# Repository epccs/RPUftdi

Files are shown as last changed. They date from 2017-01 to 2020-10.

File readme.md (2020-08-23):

# RPUusb

From <https://github.com/epccs/RPUusb>

## Overview

Alow a desktop or other host with USB to interface with [Gravimetric] that have an R-Pi header. It has two UARTs that can together operate the multi-drop serial. 

[Gravimetric]: https://github.com/epccs/Gravimetric

## Status

This board has a known problem with managers that lack power domains that allow one side to power down, that is to say if it has power and the application does not then the manager on the application board will be damaged. It is my hope that I can figure out how to use one of the new AVR-DB chips as a manager to fix this problem.

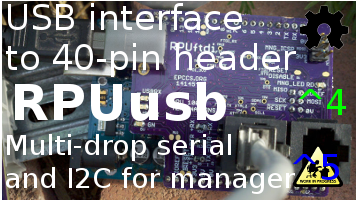
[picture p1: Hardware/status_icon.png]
Status


This is programmed with an in-circuit serial programming tool that is able to handle the 3.3V ATmega328pb target. I use an Arduino Uno with the [ArduinoISP] sketch and an SPI level shifter.

[ICSP]: https://github.com/epccs/Driver/tree/master/ICSP

[ArduinoISP]: https://github.com/arduino/Arduino/blob/master/build/shared/examples/11.ArduinoISP/ArduinoISP/ArduinoISP.ino

## [Hardware](./Hardware)

Hardware files and notes for referance.

## Example

TBD

## AVR toolchain

The core files for this board are in the /lib folder. Each example has its files and a Makefile in its own folder. The toolchain packages that I use are available on Ubuntu, Raspbian and Windows with WSL and Ubuntu installed. 

```
sudo apt-get install git make gcc-avr binutils-avr gdb-avr avr-libc avrdude
git clone https://github.com/epccs/RPUusb
```

* [gcc-avr](https://packages.ubuntu.com/search?keywords=gcc-avr)
* [binutils-avr](https://packages.ubuntu.com/search?keywords=binutils-avr)
* [gdb-avr](https://packages.ubuntu.com/search?keywords=gdb-avr)
* [avr-libc](https://packages.ubuntu.com/search?keywords=avr-libc)
* [avrdude](https://packages.ubuntu.com/search?keywords=avrdude)

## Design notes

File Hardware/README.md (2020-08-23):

# Hardware

## Overview

USB interface that plugs in place of an R-Pi. It plugs into an R-Pi header (e.g., [Gravimetric]). The CP2105 chip has two UARTs. The full-duplex multidrop bus is directly connected to the primary UART, while the secondary UART is connected to an MCU (ATmega328pb) that can act as a bridge for many of the R-Pi header pins (e.g., SPI, I2C) from the target board. A USB host can set the bootload address on the multi-drop serial with the I2C interface from the 328pb, and some other functions that an R-Pi has access to from the manager.

[Gravimetric]: https://github.com/epccs/Gravimetric

## Inputs/Outputs/Functions

* Full Duplex TX and RX from USB serial0 on R-Pi header pin 8 and 10.
* RTS and CTS from USB serial0 on R-Pi header pin 36 and 11.
* USB serial1 connects with an ATmega328pb for use with I2C/SPI.
* Fits RPUpi or Gravimetric.

## Uses

* Plugs in place of an R-Pi to allow USB from a computer to communicate with an RPU target.

# Table Of Contents

1. [Status](#status)
2. [Design](#design)
3. [Bill of Materials](#bill-of-materials)
4. [How To Use](#how-to-use)

# Status

Status RPUusb Status

```
        ^5  Done: Design (# = done), Layout, BOM, Review*, Order Boards, Assembly, Testing,
            WIP: Evaluation.
            Todo: 
            *during review the Design may change without changing the revision.
            High risk of damage to manager on application board, if manager has dual power domains that may fix
            # remove arduino headers
            # add header with 40 pin R-Pi pinout
            # swap MCU to ATmega328pb
            # swap ftdi with a dual UART port version Silabs CP2105
            # connect serial0 to RX/TX/nRTS/nCTS on R-Pi header
            # connect sierial1 to MCU's serial0
            # connect MCU's I2C0 to I2C on R-Pi header
            # connect MCU's I2C1 to the ID port on R-Pi header
            # connect MCU's SPI to SPI on R-Pi header
            # power with 3V3 from LDO and power the LDO from the USB header through the P-CH soft start. 

        ^4 Done: Design, Layout, BOM, Review*, Order Boards, Assembly, Testing, Evaluation.
           WIP: 
           Todo:  
           *during review the Design may change without changing the revision.
           location: 2017-3-17 Test Bench /w an OSEPP Uno R3

        ^3 location: 2016-10-1 Test Bench /w an OSEPP Uno R3, used to connect by CAT5 to outside parts and to bench parts as needed.
                     2017-1-5 ICP1 hacked open.
                     2017-3-17 scraped
```

Debugging and fixing problems i.e. [Schooling](./Schooling/)

Setup and methods used for [Evaluation](./Evaluation/)

# Design

The board is 0.063 thick, FR4, two layer, 1 oz copper with ENIG (gold) finish.

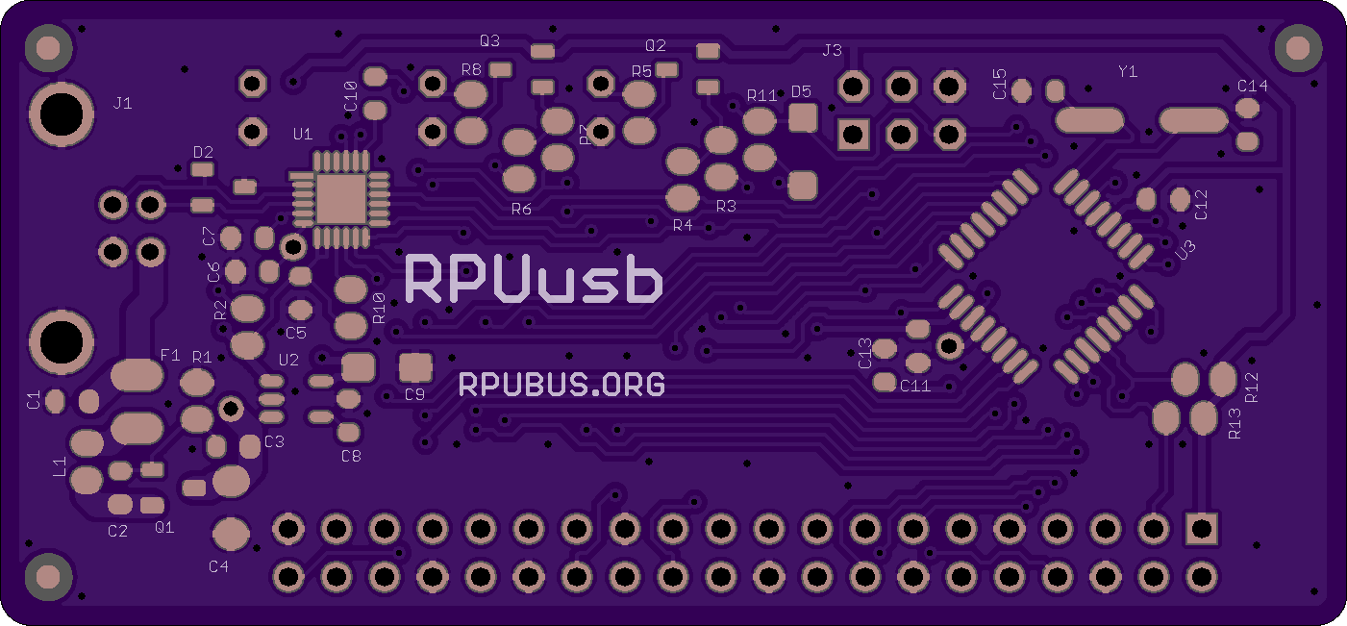
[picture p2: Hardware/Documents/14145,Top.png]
Top RPUusb Top

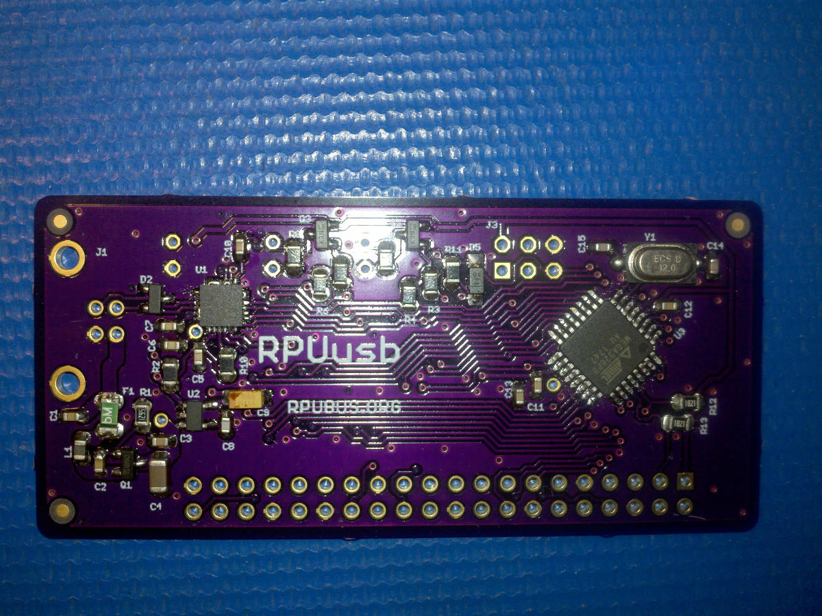
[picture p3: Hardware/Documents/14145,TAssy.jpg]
TAssy RPUusb Top Assy

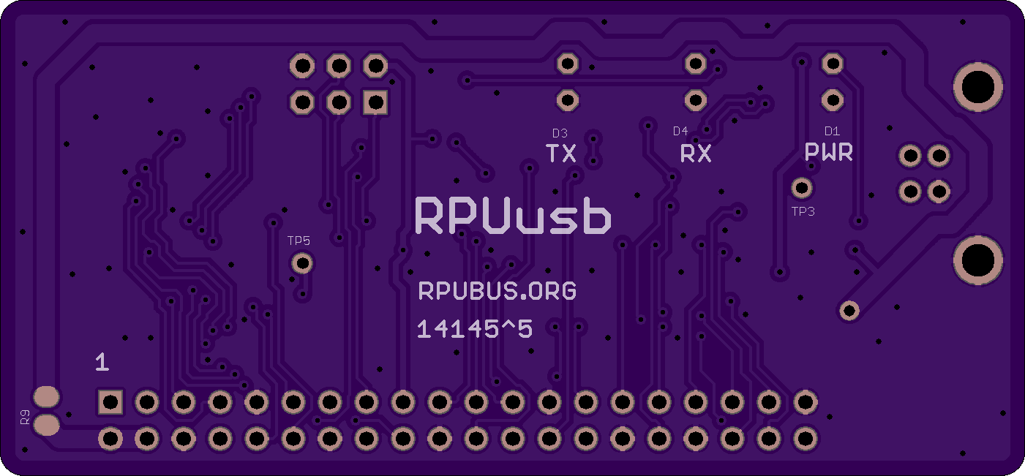
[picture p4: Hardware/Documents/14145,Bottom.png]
Bottom RPUusb Bottom

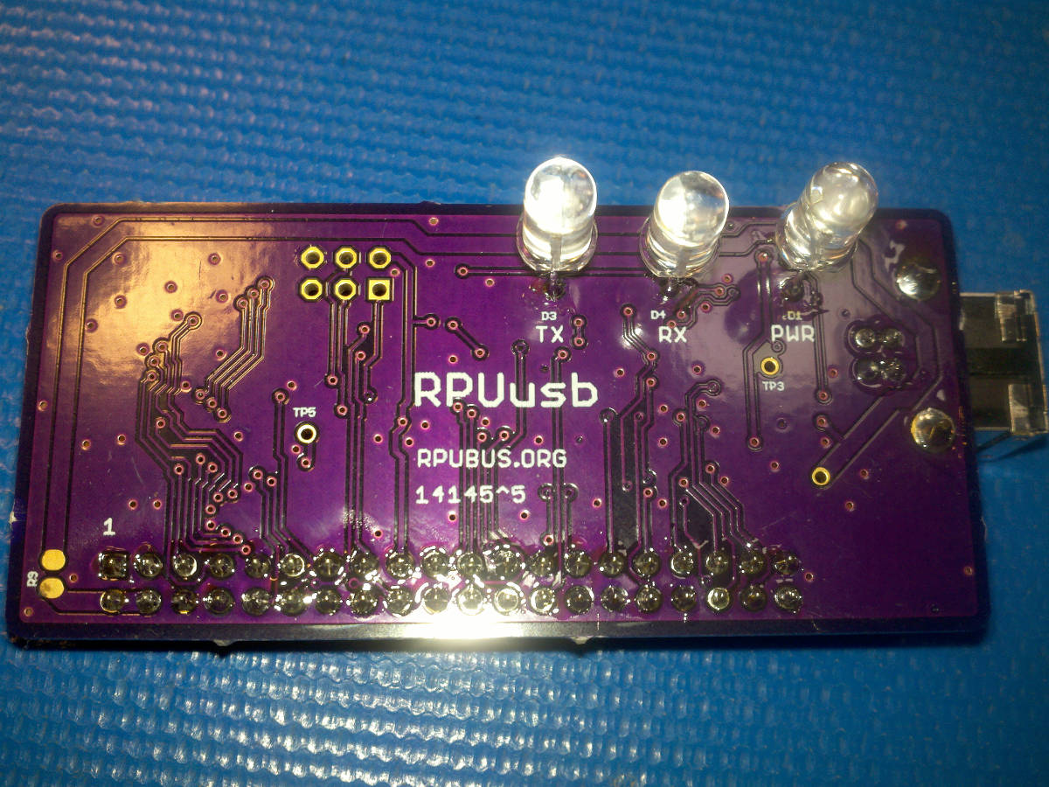
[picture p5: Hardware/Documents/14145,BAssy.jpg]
BAssy RPUusb Bottom Assy


## Mounting

```
        Plugs into the R-Pi header of a multi-drop serial board.
```

## Electrical Schematic

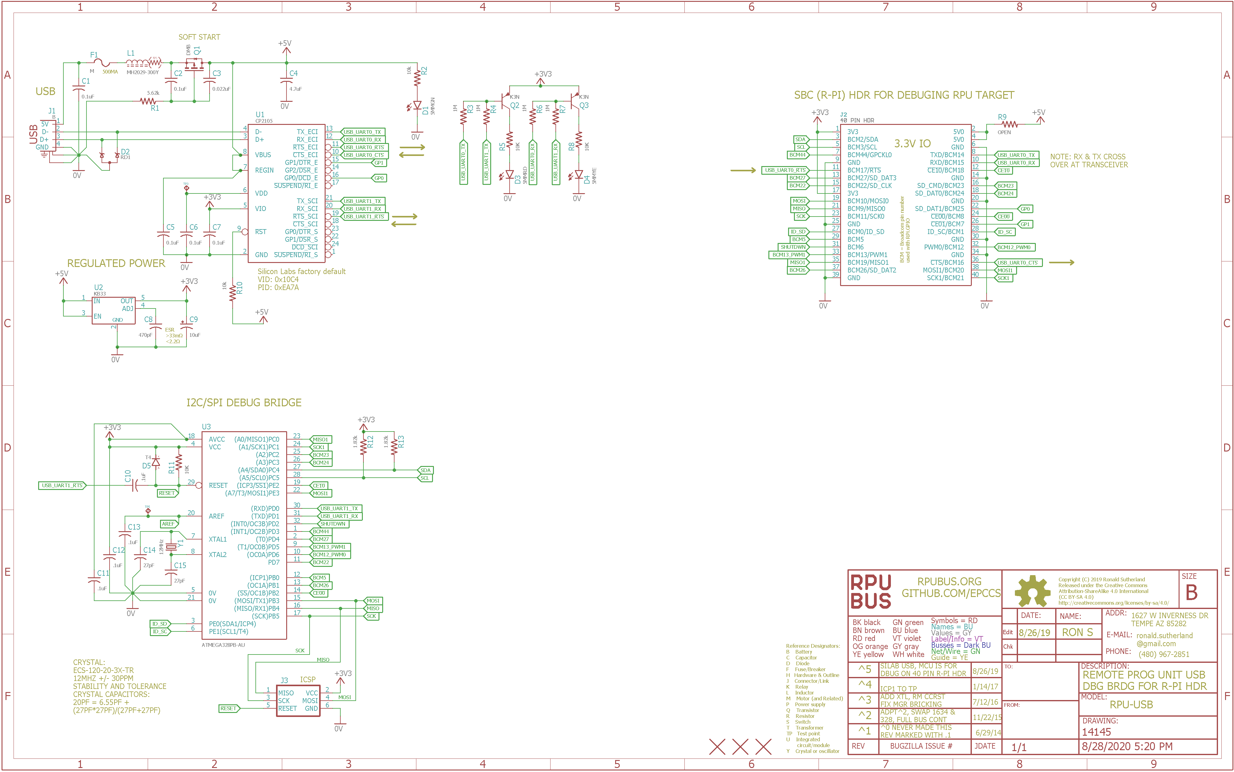
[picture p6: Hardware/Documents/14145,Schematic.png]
Schematic RPUusb Schematic


## Testing

Check correct assembly and function with [Testing](./Testing/)

# Bill of Materials

The BOM is a CVS file, import it into a spreadsheet program like LibreOffice Calc (or Excel), or use a text editor.

Option | BOM's included
----- | ----- 
A. | [BRD] 
M. | [BRD] [SMD] [HDR] 

[BRD]: ./Design/14145BRD,BOM.csv
[SMD]: ./Design/14145SMD,BOM.csv
[HDR]: ./Design/14145HDR,BOM.csv

[Order Form](https://rpubus.org/Order_Form.html)

# How To Use

TDD

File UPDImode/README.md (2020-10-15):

# UPDI mode

## Overview

The BCM23 and BCM24 pins are used by my PiUPDI board to select serial0 and UPDI programing. PiUPDI has an AVR128DA28 that is programed with [pyupdi].

[pyupdi]: https://github.com/mraardvark/pyupdi/

## Firmware Upload

Use the secondary serial port connection (see BOOTLOAD_PORT in Makefile) to reset the MCU and execute optiboot so that the 'make bootload' rule can upload a new binary image in the application area of flash memory. The bootloader runs at 38.4kbps.

``` 
sudo apt-get install make git picocom gcc-avr binutils-avr gdb-avr avr-libc avrdude
git clone https://github.com/epccs/RPUusb/
cd /Gravimetric/Applications/BCM24cntl
make all
...
avr-objcopy -j .text -j .data -O ihex blinkLED.elf blinkLED.hex
avr-objdump -h -S blinkLED.elf > blinkLED.lst
make bootload
...
avrdude done.  Thank you.
``` 

Now connect with picocom (or ilk) to send commands.

``` 
picocom -b 38400 /dev/ttyUSB1
...
/0/id?
{"id":{"name":"BMC24cntl","desc":"RPUusb (14145^5) Board /w ATmega328pb","avr-gcc":"5.4.0"}}
/0/updi
{"PiUPDI":"UPDI"}
/0/uart
{"PiUPDI":"UART"}
#exit is C-a, C-x
``` 

The Python program will need to be done so it can reconize if a R-Pi is in use or if it is an RPUusb.

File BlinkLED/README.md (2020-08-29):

# Makefile based non-blocking Blink

## Overview

Demonstration of General I/O, e.g. Blink an LED. 

It also links an Interrupt-Driven UART library for AVR Standard IO facilities, as well as some Python that sends an 'a' character to stop blinking the SCK pin. 

## Firmware Upload

Use the secondary serial port connection (see BOOTLOAD_PORT in Makefile) to reset the MCU and execute optiboot so that the 'make bootload' rule can upload a new binary image in the application area of flash memory. The bootloader runs at 38.4kbps.

``` 
sudo apt-get install make git picocom gcc-avr binutils-avr gdb-avr avr-libc avrdude
git clone https://github.com/epccs/RPUusb/
cd /RPUusb/Applications/BlinkLED
make all
...
avr-objcopy -j .text -j .data -O ihex blinkLED.elf blinkLED.hex
avr-objdump -h -S blinkLED.elf > blinkLED.lst
make bootload
...
avrdude done.  Thank you.
``` 

Next use picocom to send characters, an 'a' to stop the blinking of the SCK pin (there is no LED), characters also echo.

``` 
picocom -b 38400 /dev/ttyUSB1
...
a
#exit is C-a, C-x
```

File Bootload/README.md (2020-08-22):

# Serial Bootloader

## Overview

AVR microcontrollers are usually programmed through an In-circuit Serial Programmer (ICSP/ISP), however with this firmware loaded in your microcontroller programing can be done over a serial interface (TX/RX) without the ICSP programmer. This is called serial bootloading. 

Unfortunalty to install a serial bootloader requires an ICSP tool. Arduino has an [ArduinoISP] sketch that I load into a Arduino Uno to use as an ICSP tool.

[ArduinoISP]: https://github.com/arduino/Arduino/blob/master/build/shared/examples/11.ArduinoISP/ArduinoISP/ArduinoISP.ino

It is a two step process. First run "make fuse" which will unlock the boot flash section and set fuses (LOW, HIGH, EXTENDED). The changed fuse setting will switch operation form the internal oscilator to the exteranl crystal, if it is missing the MCU will be locked up. The second step is "make isp" which will load the bootloader and lock the boot flash section, which should prohibit the Store Program Memory (SPM) instruction from running in the boot flash section. 

    WARNING: programing these fuse valuse will lock up the MCU when the crystal is missing or damaged.

## License 

The main.c is GPL while boot.h is BSD (since the code is the documentation just read the license in it).

## Firmware Upload

With ISP tool connected.

``` 
sudo apt-get install make git gcc-avr binutils-avr gdb-avr avr-libc avrdude
git clone https://github.com/epccs/RPUusb/Bootloader
cd /RPUno/Bootloader
make all
make isp
...
avrdude -v -p atmega328pb -C +../lib/avrdude/328pb.conf -c stk500v1 -P /dev/ttyACM0 -b 19200 -U eeprom:r:optiboot_rpuusb_atmega328pb_eeprom.hex:i
...
avrdude: safemode: Fuses OK (E:FD, H:DE, L:FF)
...
avrdude -v -p atmega328pb -C +../lib/avrdude/328pb.conf -c stk500v1 -P /dev/ttyACM0 -b 19200 -e -U lock:w:0xFF:m -U lfuse:w:0xFF:m -U hfuse:w:0xDE:m -U efuse:w:0xFD:m
...
avrdude: safemode: Fuses OK (E:FD, H:DE, L:FF)
...
avrdude -v -p atmega328pb -C +../lib/avrdude/328pb.conf -c stk500v1 -P /dev/ttyACM0 -b 19200 -e -U flash:w:optiboot_rpuusb_atmega328pb_-b38400UL_F_CPU12000000UL.hex -U lock:w:0xEF:m
...
avrdude done.  Thank you.
``` 

The bootloader is from MCUdude
https://github.com/MCUdude/optiboot_flash

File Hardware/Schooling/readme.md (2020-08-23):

# Description

Some lessons I learned doing RPUusb.

# Table Of Contents:

1. ^5 Smoke
1. ^5 Names
1. ^4 Power Chopping
1. ^3 Baud Rate
1. ^3 Bus Manager ICP1 Used to Hault Host
1. ^3 FT231X Problem Toggling nDTR and nRTS
1. ^2 I2C Level Converter
1. ^2 Brick Bus Management MCU

## ^5 Smoke

Do not power the RPUusb board (e.g., so remove the USB plug before) first. Power the application (Gravimetric) board and then plug in the USB. This problem is going to take some time to understand. First, I have to figure out which part(s) let out smoke; it is not apparent.

Found a damaged place, it is the manager (m328pb on Gravimetric^2) over the power pin four, which has a bump above it where the smoke was let out. I have found a few paths (TWI1 which is used for SMBus) where the current from RPUusb could flow into an unpowered manager. I suspect that when I had the USB powered and the Gravimetric unpowered, it damaged the manager, and when I powered the Gravimetric, the manager let out its smoke since it was degraded. I think this could happen without severely damaging other parts, so I will try to replace the Gravimetric manager.

This is probably when a second power domain on an MCU makes  sense. The new AVR-DB series offers it but that will need to be an update, also I think it will need to be the manager on Gravimetric that gets the update.

Replaceing the manager on Gravimetric did fix the problem so if a AVR-DB has two I2C ports on sepreate power domains than I may be fix this. An externaly powered R-Pi would have the same problem I suspect, so this needs fixed (but not on the RPUusb board, it needs fixed on the application board.)

## ^5 Names

RPUftdi has been renamed RPUusb because I am not using an FTDI chip for this. It was probably a bad idea to use the company name in the board name like that.

## ^4 Power Chopping

Transceivers start and stop (chop) the power flow over the USB cable; occasionally it results in a reset of the host computer. Mixing power and data is risky; the next version of this board should not power the transceivers from the USB.

## ^3 Baud Rate 

The [Bit Rate] error at 115.2k is too high (though it mostly works). I have not seen errors on Windows yet but am seeing them on Linux. Looking at the [Rate Calculator] I see 76.8k is very good, but the picocom packaged on Ubuntu does not support it. The next very good rate is 38.4k which picocom does support. The bootloader does a CRC check with each line in the hex file so running it 115.2k is fine, it will redo the chunks with errors. However, I don't want to see any errors while running commands (that would look bad during a demo).

Note: [Baud] is the wrong term, but is the one everyone knows.

[Rate Calculator]: http://wormfood.net/avrbaudcalc.php
[Baud]: https://en.wikipedia.org/wiki/Baud
[Bit Rate]: https://en.wikipedia.org/wiki/Bit_rate#Gross_bit_rate

## ^3 Bus Manager ICP1 Used to Hault Host

Connect bus manager ICP1 pin to a test point rather than DTR transceiver. RPUpi is using it to shutdown/halt the host computer. Cut the indicated PCB trace to open the ICP1 pin.

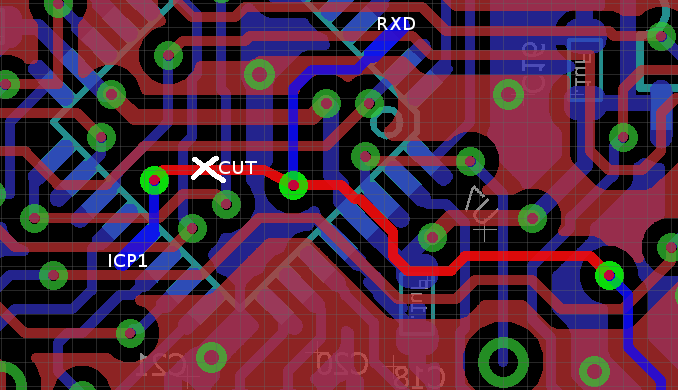
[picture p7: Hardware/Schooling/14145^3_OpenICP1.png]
Open ICP1


## ^3 FT231X Problem Toggling nDTR and nRTS

This problem is not hardware, it was caused because I wrote the Host2Local firmware as though nSS was connected to nRESET directly but that is not the case. I have an open drain buffer between them so when  nSS went high impedance it did not pull up the buffer and the MCU did not turn on after reset. I am still confused why nDTR and nRTS did not pull up but they seem to be working as expected (on both Linux and Windows) now that I set nSS as an output with a high and low state (as opposed to a low and high-z state).

## ^2 I2C Level Converter

If I2C has a pull-up to 3.3V then the level converter is not needed. Arduino's IDE Wire C++ class turns on the ATmega328 internal pull-ups which raise the voltage above 3.3, e.g. I read 3.5V for an undriven bus, which is probably fine but it confused and was not expected. After un-wrapping the TWI code from the Wire class and getting it to run with the vanilla avr-libc I found the pull-up code and turned it into an option during initialization.

## ^2 Brick Bus Management MCU

R20 (jumpered by default) was used to connect a local MCU (SS from a Uno) to reset the bus manager. Unfortunaly when the bootloader programs the local boad it seems to play with the SPI interface and ends up setting the flages of the bus manager to zero. This effectivly bricks the part, though the flags can be set with a parall programing setup (which I may do after collecting a few bricks).

SPI to the bus manager has been removed.

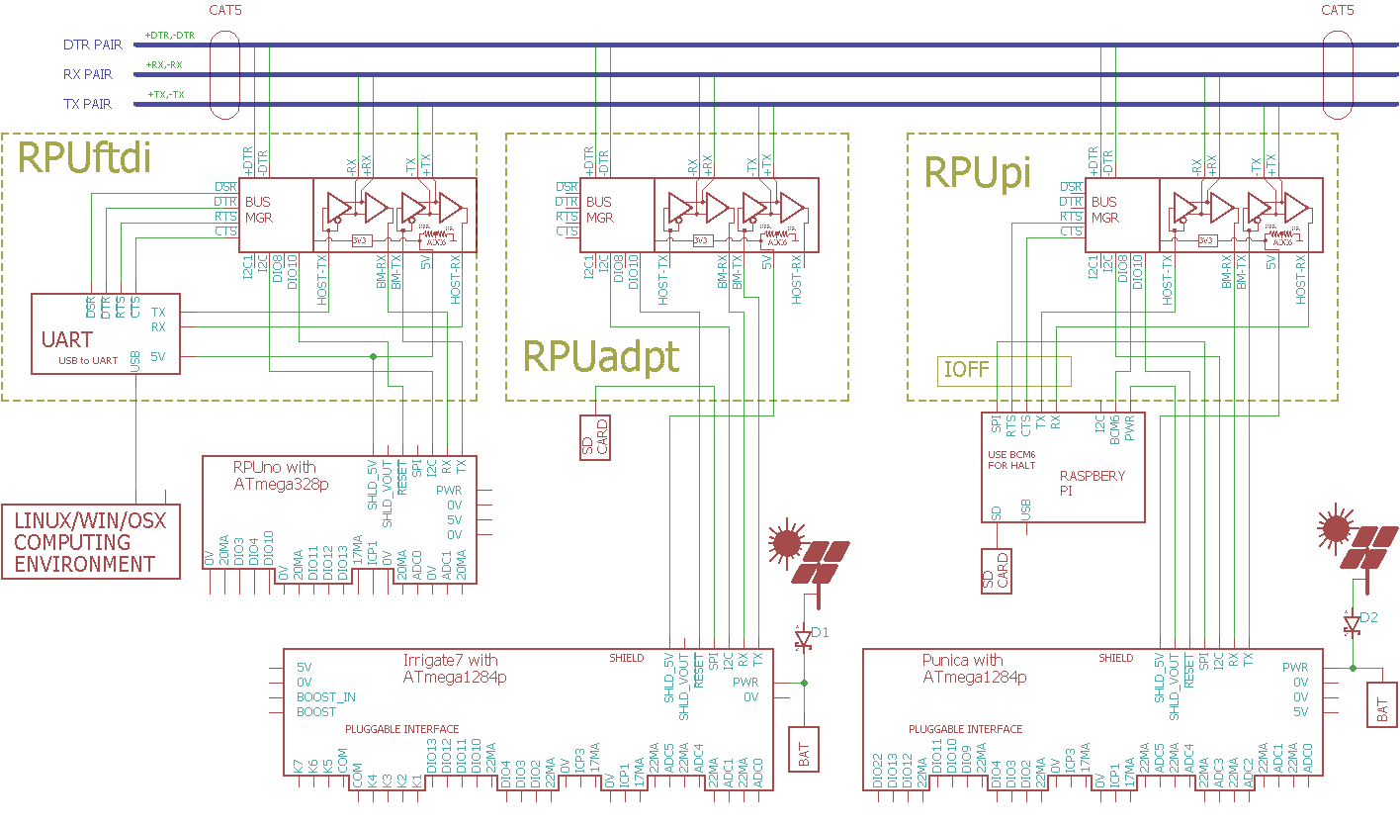
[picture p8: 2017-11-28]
Hardware/Documents/MultiDrop.png

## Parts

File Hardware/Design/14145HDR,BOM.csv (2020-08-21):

LINE | REF | QTY | TYP | PN | MFG@PN | DESCRIPTION | NOTES | COST EA | LINE COST | BIN
 |  |  |  |  |  | RPUusb Headers |  |  | TOTAL
 |  |  |  |  |  | 8/29/19 (14145^5) |  |  | =SUM(J5:J100)
1 | D1 | 1 | D-LED | 5MMGN | CREE@C503B-GCN-CY0C0791 | LED GREEN 5MM 3.2V@20MA | (1) | 0.21 | =C5*I5 | ONESHOT
2 | D3 | 1 | D-LED | 5MMRD | CREE@C503B-RCN-CW0Z0AA1 | LED RED 5MM 2.1V@20MA | (1) | 0.129 | =C6*I6 | ONESHOT
3 | D4 | 1 | D-LED | 5MMYE | CREE@C503B-AAN-CA0B0342 | LED AMBER 5MM 2.1V@20MA | (1) | 0.1342 | =C7*I7 | SHOP
4 | J1 | =1 | J-USB | B | MOLEX@0670688000 | USB B THROUGH HOLE | (1) | 1.199 | =C8*I8 | FTDI
5 | J2 | =1*20/36 | J-HDR2.54mm | PBC36DAAN | SULLINS@PBC36DAAN | CONN HEADER MALE BRKWAY .1IN AA 36X2POS 1 SET OF 20X2 | (1 4) | 3.774 | =C9*I9 | IRRIGATE7
6 | J3 | =0*3/36 | J-HDR2.54mm | PBC36DAAN | SULLINS@PBC36DAAN | CONN HEADER MALE BRKWAY .1IN AA 36X2POS 1 SET OF 3X2 | (1 4) | 3.774 | =C10*I10 | IRRIGATE7
 |  |  |  |  |  | NOTES
 |  |  |  |  |  | (1) Alternate part with same or better rating allowed
 |  |  |  |  |  | (4) Cut 36 pin to needed size

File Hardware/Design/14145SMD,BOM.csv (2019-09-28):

LINE | REF | QTY | TYP | PN | MFG@PN | DESCRIPTION | NOTES | COST EA | LINE COST | BIN
 |  |  |  |  |  | RPUusb SMD |  |  | TOTAL
 |  |  |  |  |  | 8/29/19 (14145^5) |  |  | =SUM(J5:J100)
1 | C1 C2 C5 C6 C7 C10 C11 C12 C13 | 9 | C-C | 0603X7R50V104K | TDK@C1608X7R1H104K080AA | CAP CER 0.1UF 50V 10% X7R 0603 | (1) | 0.0055 | =C5*I5 | ADPT
2 | C3 | 1 | C-C | 0603X7R50V223K | TDK@C1608X7R1H223K080AA | CAP CER 0.022UF 50V 10% X7R 0603 | (1) | 0.0148 | =C6*I6 | FTDI
3 | C4 | 1 | C-C | 1206X7R50V475K | TAIYO@UMK316AB7475KL-T | CAP CER 4.7UF 50V 10% X7R 1206 | (1) | 0.115 | =C7*I7 | FTDI
4 | C8 | 1 | C-C | 0603NPO50V471J | MURATA@GRM1885C1H471JA01D | CAP CER 470PF 50V 5% NPO 0603 | (1) | 0.0202 | =C8*I8 | ADPT
5 | C9 | 1 | C-T | 106A | AVX@TPSA106K010R0900 | CAP TANT 10UF 10V 10% ESR .9OHM 1206 | (1) | 0.3575 | =C9*I9 | ADPT
6 | C11 C12 | 2 | C-C | 0603NPO50V270J | SAMSUNG@CL10C270JB8NNNC | CAP CER 27PF 50V 5% NPO 0603 | (1) | 0.0067 | =C10*I10 | RPUNO
7 | D2 | 1 | D-TVS | RD1 | DIODES@DESDA5V3L-7 | TVS DIODE 3V 15V SOT23 | (1) | 0.1286 | =C11*I11 | FTDI
8 | D5 | 1 | D-GP | T4 | DIODES@1N4148W-7-F | DIODE SWITCH 100V 0.15A SOD123 | (1) | 0.0601 | =C12*I12 | CC01
9 | F1 | 1 | F-RST | bM | BEL@0ZCJ0050FF2G | FUSE RESETTABLE 500MA 8V 1206 | (1) | 0.0972 | =C13*I13 | FTDI
10 | L1 | 1 | L-FB | MH2029-300Y | BORNS@MH2029-300Y | FERRITE SMDBEAD 30OHM@100MHZ 3A 0805 | (1) | 0.0272 | =C14*I14 | FTDI
11 | Q1 | 1 | Q-PCH | DMB | DIODES@DMP3098L-7 | MOSFET P-CH 3.8A 30V SOT23 | (1) | 0.1482 | =C15*I15 | FTDI
12 | Q2 Q3 | 2 | Q-PNP | K3N | DIODES@MMBT3906-7-F | TRANSISTOR PNP GP 40V 200MA SOT23 | (1) | 0.0247 | =C16*I16 | HT
13 | R1 | 1 | R-C | 0805KX5621 | YAGEO@RC0805FR-075K62L | RESISTOR CHIP 1% 5K62OHM 0805 | (1) | 0.0064 | =C17*I17 | CC01
14 | R2 R5 R8 R10 R11 | 5 | R-C | 0805KX1002 | YAGEO@RC0805FR-0710KL | RESISTOR CHIP 1% 10KOHM 0805 | (1) | 0.0025 | =C18*I18 | ADPT
15 | R3 R4 R6 R7 | 4 | R-C | 0805KX1004 | YAGEO@RC0805FR-071ML | RESISTOR CHIP 1% 1MOHM 0805 | (1) | 0.0025 | =C19*I19 | MT
16 | R9 | 0 | R-C | OPEN |  |  | () | 0.0 | =C20*I20 | NA
17 | R12 R13 | 2 | R-C | 0805KX1821 | YAGEO@RC0805FR-071K82L | RESISTOR CHIP 1% 1K82OHM 0805 | (1) | 0.0064 | =C21*I21 | RPUPI
18 | U1 | 1 | U-TRANSCEIVER | CP2105 | SILABS@CP2105-F01-GMR | TRANSCEIVER USB DUAL UART 24QFN | (1) | 1.56 | =C22*I22 | FTDI
19 | U2 | 1 | U-DCDC | KB33 | MICREL@MIC5205-3.3YM5 | REG ULDO 3V3 150MA SOT23-5 | (1) | 0.34 | =C23*I23 | ADPT
20 | U3 | 1 | U-AVR | ATMEGA328PB | ATMEL@ATMEGA328PB-AU | MCU AVR8 32KB FLASH 20MHZ 32TQFP | (1) | 1.27 | =C24*I24 | ADPT
21 | Y1 | 1 | Y-XTL | 12MHZ20 | ECS@ECS-120-20-3X-TR | CRYSTAL 12MHZ 20PF 30PPM CSM-3X | (1) | 0.315 | =C25*I25 | ADPT
 |  |  |  |  |  | NOTES
 |  |  |  |  |  | (1) Alternate part with same or better rating allowed

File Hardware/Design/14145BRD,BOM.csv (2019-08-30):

LINE | REF | QTY | TYP | PN | MFG@PN | DESCRIPTION | NOTES | COST EA | LINE COST | BIN
 |  |  |  |  |  | RPUusb Board |  |  | TOTAL
 |  |  |  |  |  | 8/29/19 (14145^5) |  |  | =SUM(J5:J100)
1 |  | =1/3 | BOARD | OSHPARK |  | PCB 2 LAYER ENIG 3 COPY | () | 18.20 | =C5*I5 | FTDI
 |  |  |  |  |  | NOTES

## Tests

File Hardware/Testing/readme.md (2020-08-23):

# Description

This is a list of Test preformed on each RPUftdi after assembly.

# Table of References

# Table Of Contents:

1. Basics
1. Assembly check
1. IC Solder Test
1. Bias USB 5V and Check LDO Regulators
1. USB Power Up
1. Set Fuse and load Bootloader
1. Load i2c-debug into the MCU at secondary UART

## Basics

These tests are for an assembled RPUftdi board 14145^5 which may be referred to as a Unit Under Test (UUT). If the UUT fails and can be reworked then do so, otherwise it needs to be scraped. 

**Warning: never use a soldering iron to rework ceramic capacitors due to the thermal shock.**
    
Items used for test.

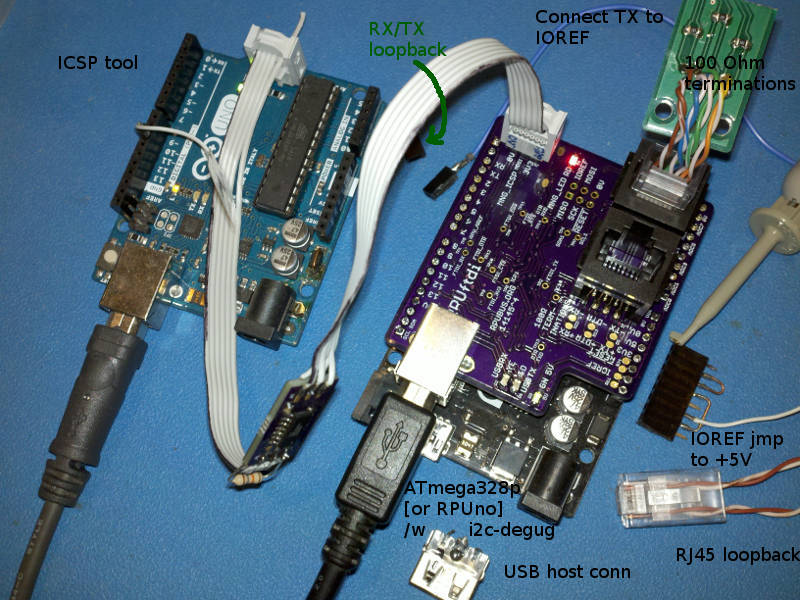
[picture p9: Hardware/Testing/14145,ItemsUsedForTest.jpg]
ItemsUsedForTest RPUusb Items Used For Test


## Assembly check

After assembly check the circuit carefully to make sure all parts are soldered and correct, note that the device making is labeled on the schematic and assembly drawing.

## IC Solder Test

Check continuity between pin and pad by measuring the reverse body diode drop from 0V (aka ground) and all other IC pads not connected to 0V. This value will vary somewhat depending on what the pin does, but there is typically an ESD diode to ground or sometimes a body diode (e.g. open drain MOSFET), thus a value of .3V to .7V is valid to indicate a solder connection. Note the RS485 drivers will show high impedance on the differential lines, so skip those.

## Bias USB 5V and Check LDO Regulators

Connect a 5V supply with CC mode set at 30mA to the USB input. Verify that the 5V gets through the fuse and soft start circuit to the +5V pin. Turn off power. 

Connect a 5V supply with CC mode set at 30mA to the the USB +5V input. Measure that the the MIC5205 (U2) linear regulator has 3.3V (J2 pin 1). Measure the input current of a blank MCU. Turn off power.

```
{   "I_IN_BLANKMCU_mA":[1.44,],
    "LDO_V":[3.41,] }
^4
{   "I_IN_BLANKMCU_mA":[4.5,4.5,4.3,4.4,],
    "LDO_V":[3.3,3.3,3.28,3.28,] }
```

## USB Power Up

On Linux use the dmesg command to see latest device mesages then plug the USB input to a powered hub that was previously connected and use dmesg to verify that the new USB port shows up.

```
dmesg
...
[11543.622763] usb 2-2: new full-speed USB device number 4 using uhci_hcd
[11543.806214] usb 2-2: New USB device found, idVendor=10c4, idProduct=ea70, bcdDevice= 1.00
[11543.806217] usb 2-2: New USB device strings: Mfr=1, Product=2, SerialNumber=5
[11543.806220] usb 2-2: Product: CP2105 Dual USB to UART Bridge Controller
[11543.806222] usb 2-2: Manufacturer: Silicon Labs
[11543.806224] usb 2-2: SerialNumber: 00B3EDE8
[11543.871127] usbcore: registered new interface driver cp210x
[11543.872699] usbserial: USB Serial support registered for cp210x
[11543.873601] cp210x 2-2:1.0: cp210x converter detected
[11543.881730] usb 2-2: cp210x converter now attached to ttyUSB0
[11543.882017] cp210x 2-2:1.1: cp210x converter detected
[11543.889340] usb 2-2: cp210x converter now attached to ttyUSB1
[38868.129478] usb 2-2: USB disconnect, device number 4
[38868.129765] cp210x ttyUSB0: cp210x converter now disconnected from ttyUSB0
[38868.133806] cp210x 2-2:1.0: device disconnected
[38868.134540] cp210x ttyUSB1: cp210x converter now disconnected from ttyUSB1
[38868.134679] cp210x 2-2:1.1: device disconnected
[38890.722140] usb 2-2: new full-speed USB device number 5 using uhci_hcd
[38890.905536] usb 2-2: New USB device found, idVendor=10c4, idProduct=ea70, bcdDevice= 1.00
[38890.905539] usb 2-2: New USB device strings: Mfr=1, Product=2, SerialNumber=5
[38890.905542] usb 2-2: Product: CP2105 Dual USB to UART Bridge Controller
[38890.905544] usb 2-2: Manufacturer: Silicon Labs
[38890.905546] usb 2-2: SerialNumber: 00B3EDE8
[38890.911642] cp210x 2-2:1.0: cp210x converter detected
[38890.918612] usb 2-2: cp210x converter now attached to ttyUSB0
[38890.920600] cp210x 2-2:1.1: cp210x converter detected
[38890.927608] usb 2-2: cp210x converter now attached to ttyUSB1
...
```

## Set MCU Fuse

Install Git and AVR toolchain on Ubuntu (20.04). 

```
sudo apt-get install git gcc-avr binutils-avr gdb-avr avr-libc avrdude
```

Clone the RPUftdi repository.

```
cd ~
git clone https://github.com/epccs/RPUusb
cd RPUusb/Bootload
```

Connect a USB host to supply power. Connect the ICSP tool (J3). The MCU needs its fuses set, so run the Makefile rule to do that. 

```
make fuse
```

Next load the bootloader

```
# a copy of the hex file is in the repo
[make all]
make isp
```

Disconnect the ICSP tool and measure the input current for 12Mhz crystal at 3.3V. It takes a long time to settel.

```
{   "I_IN_MCU_12MHZ-CRYSTAL_mA":[8.9,]}
^4
{   "I_IN_MCU_12MHZ_LP-CRYSTAL_mA":[7.3,7.3,7.2,7.1,7.1,7.2,7.1,]}
^3
{   "I_IN_MCU_8MHZ_INTRN_mA":[6.3,6.2,6.0,6.1]}
```

Some MCU pins are floating.

## Load i2c-debug into the MCU at secondary UART

Plug the DUT into a Gravimetric board (or other simular applicaion board). Power the application board first, then connect the USB from a host computer to the RPUusb.

Warning: powering the RPUusb first will damage the manager on the application board (unless I figure out how to use an AVR-DB for the manager, which has dual power domains.)

Use the command line to upload the i2c-debug firmware after building it.

```
cd ~RPUusb/i2c-debug
make all
make bootload
```

Use picocom to connect. Exit picocom with C-a, C-x.

```
picocom -b 38400 /dev/ttyUSB1
...
Terminal ready
i2c-debug at addr 48: commands include
/0/id?
...
/0/id?
{"id":{"name":"I2Cdebug^2","desc":"RPUusb (14145^5) Board /w ATmega328pb","avr-gcc":"5.4.0"}}
```

Scan for the manager on the applicaion board. It is on I2C0 of the MCU we are talking to on USB UART1.

```
/0/iscan?
{"scan":[{"addr":"0x2A"}]}
```

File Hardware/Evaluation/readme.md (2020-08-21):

# Description

This shows the setup and method used for evaluation of RPUusb.

# Table of References

# Table Of Contents:

1. ^5 Mounting
1. ^4 Remote Reset of an RPUno
1. ^4 Mounting
1. ^4 Bus Manager Running at 12MHz
1. ^3 Proof of Concept
1. ^2 I2C Slave Operation
1. ^2 RS485 Full Duplex Loopback

## ^5 Mounting

Arduino style headers have been removed; the 40pin header is for a Raspberry Pi (or other SBC with that style pinout). The RPUusb (renamed from RPUftdi) is now set up to interface with the 20x2 header. It has a dual UART USB chip (not FTDI hence the name change) where the primary serial port is for the multidrop, and the secondary connects to a 328pb that interfaces its I2C pins where the R-Pi does (also SPI). The secondary serial is picky about baud rates, have a look at the CP2105 datasheet for details.

https://www.silabs.com/documents/public/data-sheets/CP2105.pdf

## ^4 Remote Reset of an RPUno

I used an RPUftdi^4 to remote reset an RPUno^6 with an RPUadpt^5 wired to a K3^2 board. A quick video shows picocom used to do the remote reset. 

[^4 Remote Reset Video](http://rpubus.org/Video/RPUno%5E6_RPUadpt%5E5_RPUftdi%5E4_K3%5E2_RemoteReset.mp4 "^4 Remote Reset Video")

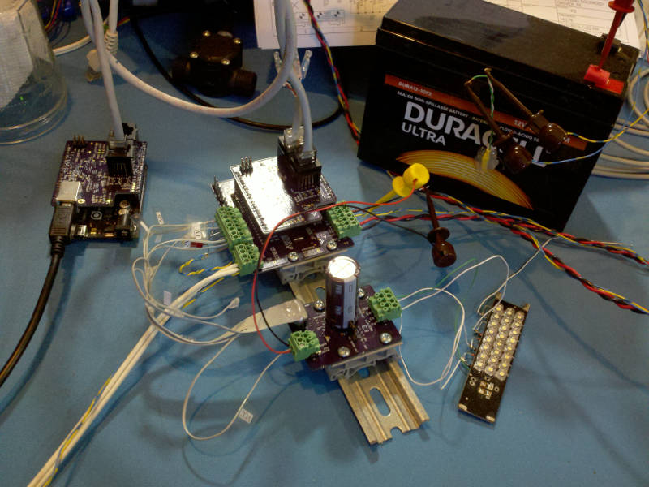
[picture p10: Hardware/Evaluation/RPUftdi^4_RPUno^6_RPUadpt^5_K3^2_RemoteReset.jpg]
^4 Remote Reset


After the reset, the bootloader runs for a few seconds and then passes control to the [Solenoid] firmware which reads an address from the RPUadpt shield over I2C and cycles through each latching coil to place them in a known state. Reading the address from RPUadpt also lets the bus manager on that board broadcast a byte on the RS-485 bus management pair (DTR) that ends the lockout placed on other devices to allow a point to point bootload connection (i.e. a return to normal point to multipoint mode).

[Solenoid]: https://github.com/epccs/RPUno/tree/master/Solenoid

## ^4 Mounting

Mounts on an RPUno or Irrigate7 as expected.

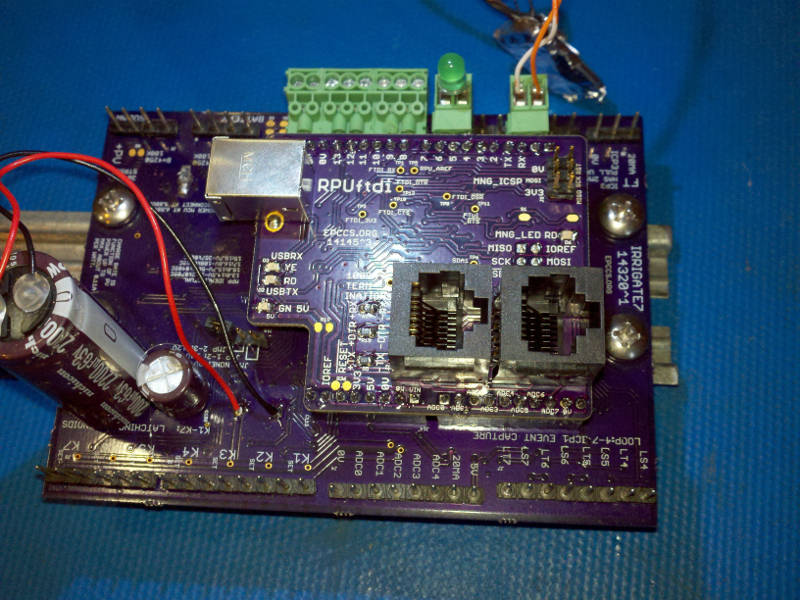
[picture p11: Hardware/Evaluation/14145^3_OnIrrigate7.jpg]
Irrigate7 Mount


Mounts on an Uno with the extra pins dangling over (they are not used on the shield). 

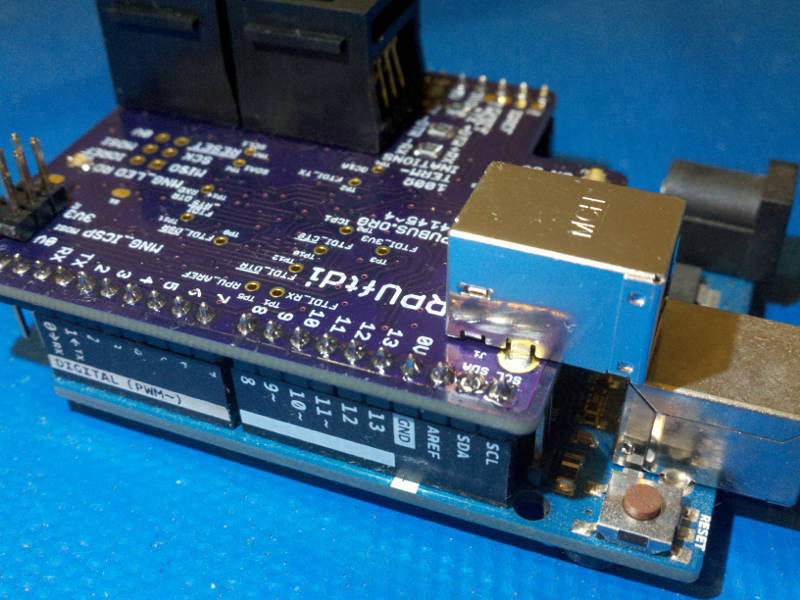
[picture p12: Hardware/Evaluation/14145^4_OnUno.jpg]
Uno Mount


Typically I use the RPUftdi with an Uno clone since I don't have a solar panel next to my computer. The clone is powered from the USB connection on the RPUftdi board (do not connect the USB on the clone).

## ^4 Bus Manager Running at 12MHz

Placed a 12MHz crystal on the revision 4 boards. The [Rate Calculator] shows zero framing error at 125k or 250k bits per second. Both non-standard rates that do not work with picocom 1.7. Since picocom does not handle half duplex control it really does not mater,  so I'm going to try 250k.

[Rate Calculator]: http://wormfood.net/avrbaudcalc.php

## ^3 Proof of Concept

The proof of concept (e.g. Multi-Drop Remote Bootload) used [Host2Remote] firmware on a RPUftdi^3 and [i2c-debug] on its bare metal MCU board (an OSEPP Uno R3 from fry's electronics). The remote device has [Remote] firmware on a RPUadpt^3 board mounted on an Irrigate7^1 (which is an ATmega1284p with xboot). The firmware bootloaded onto the Irrigate7^1 is [BlinkLED].

[Remote Bootload Video](http://rpubus.org/Video/14145%5E3_RPU_RemoteBootload.mp4 "Remote Bootload Video")

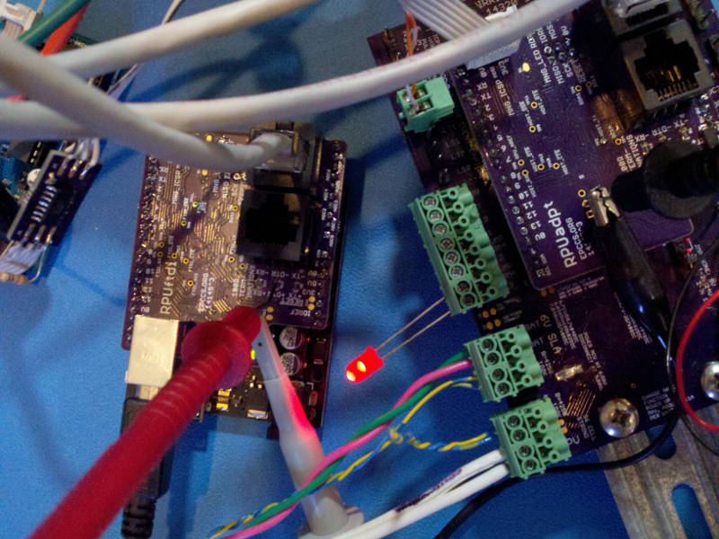
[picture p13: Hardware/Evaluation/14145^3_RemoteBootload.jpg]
Remote Bootload


[Host2Remote]: https://github.com/epccs/RPUftdi/tree/master/Host2Remote
[Remote]: https://github.com/epccs/RPUadpt/tree/master/Remote
[BlinkLED]: https://github.com/epccs/Irrigate7/tree/master/BlinkLED

## ^2 I2C Slave Operation

I2C Slave operation has been checked with the [TwiSlave] firmware on a RPUftdi^2 with [i2c-debug] on an OSEPP Uno R3 (from fry's electronics).

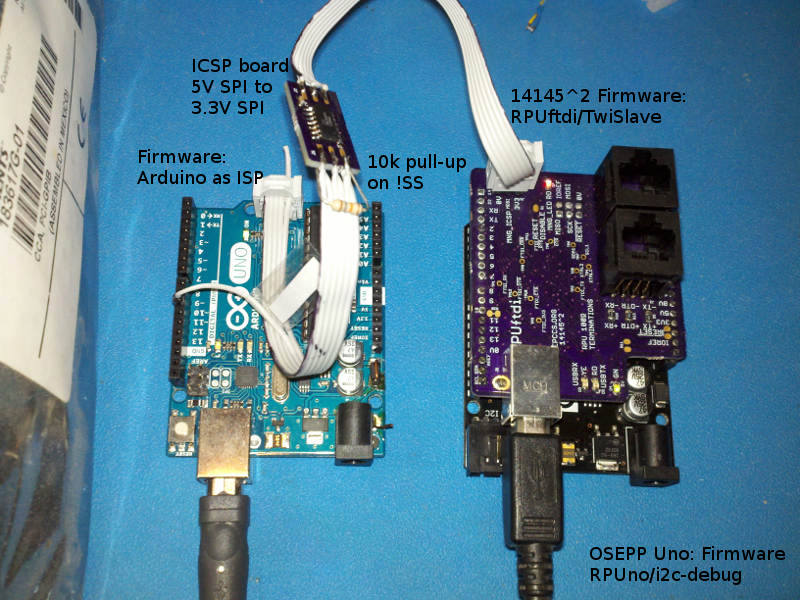
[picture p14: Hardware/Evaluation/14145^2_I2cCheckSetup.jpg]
I2C Check Setup


[TwiSlave]: https://github.com/epccs/RPUftdi/tree/master/TwiSlave
[i2c-debug]: https://github.com/epccs/RPUno/tree/master/i2c-debug

## ^2 RS485 Full Duplex Loopback

Checking voltage levels and sending data through a loop back shows the RS485 TX and RX Transceivers do what is needed. Firmware Host2Local enables both TX and RX transceiver driver and receiver to check this.

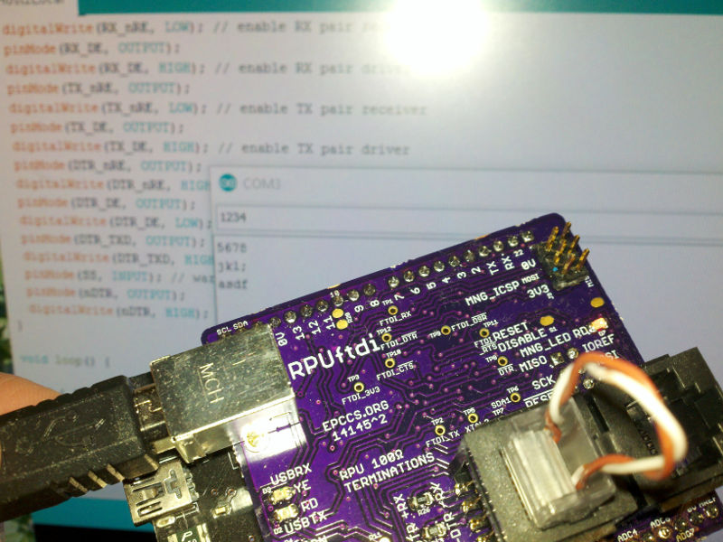
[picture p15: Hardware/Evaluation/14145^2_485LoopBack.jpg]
485 Loop Back


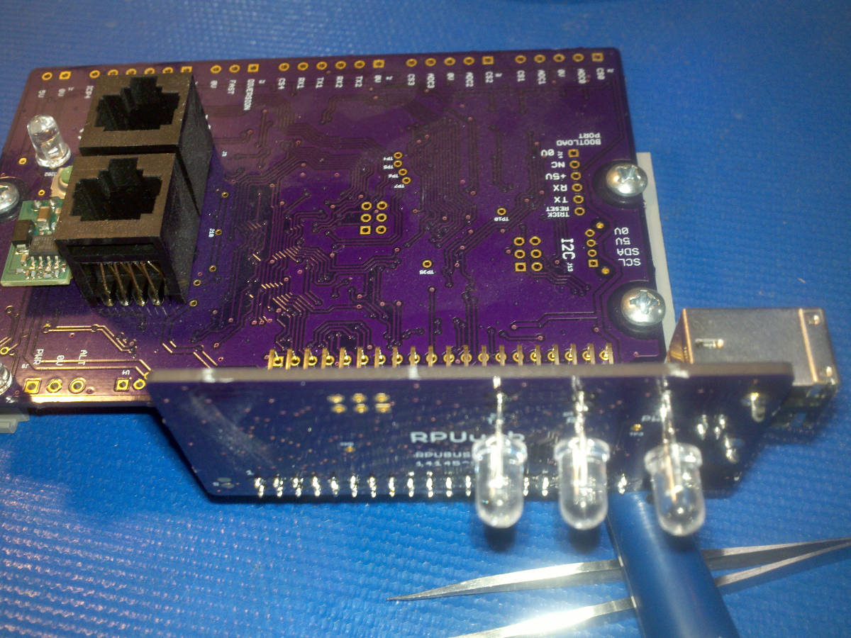
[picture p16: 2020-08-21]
Hardware/Evaluation/14145^5_OnGravimetric.jpg

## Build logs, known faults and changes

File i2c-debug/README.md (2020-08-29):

# I2C-Debug 

## Overview

2-wire Serial Interface (TWI, a.k.a. I2C) uses pins with SDA and SCL functions. 

The peripheral control software provides interrupt-driven asynchronous I2C functions that can operate without blocking. It can also work with an interleaving receive buffer for SMBus block transactions that to mitigate problems involving clock stretching (e.g., for R-Pi Zero). This application uses both TWI0 and TWI1 hardware. TWI0 is connected to where the R-Pi SMBus would operate, and TWI1 is where the Identification interface goes.

## Firmware Upload 

Use the secondary serial port connection (see BOOTLOAD_PORT in Makefile) to reset the MCU and execute optiboot so that the 'make bootload' rule can upload a new binary image in the application area of flash memory. The bootloader runs at 38.4kbps.

``` 
sudo apt-get install make git picocom gcc-avr binutils-avr gdb-avr avr-libc avrdude
git clone https://github.com/epccs/RPUusb/
cd /RPUusb/Applications/i2c-debug
make all
...
avr-objcopy -j .text -j .data -O ihex i2c-debug.elf i2c-debug.hex
avr-objdump -h -S i2c-debug.elf > i2c-debug.lst
make bootload
...
avrdude done.  Thank you.
``` 

Now connect with picocom (or ilk).

``` 
#exit is C-a, C-x
picocom -b 38400 /dev/ttyUSB1
...
/0/iscan?
``` 

# Commands

Commands are interactive over the serial interface at 38400 baud rate. The echo will start after the second character of a new line. 

## /\[rpu_address\]/\[command \[arg\]\]

rpu_address is taken from the manager (e.g. get_Rpu_address() which is included form ../lib/rpu_mgr.h). The value of rpu_address is used as a character in a string, which means don't use a null value (C strings are null terminated) as an adddress. The ASCII value for '1' (0x31) is easy and looks nice, though I fear it will cause some confusion when it is discovered that the actual address value is 49.

Commands and their arguments follow.

## /0/id? \[name|desc|avr-gcc\]

identify 

``` 
/1/id?
{"id":{"name":"I2C1debug^2","desc":"Gravimetric (17341^1) Board /w ATmega324pb","avr-gcc":"5.4.0"}}
```

## /0/i1scan?

Scan of I2C bus shows all 7 bit devices found (nothing is on the bus).

``` 
/1/i1scan?
{"scan":[]}
```

Note: the address is right-shifted so that it does not include the Read/Write bit. 

## /0/i1addr 0..127

Set an I2C address for the masster to access. 

``` 
/1/i1addr 41
{"master_address":"0x29"}
```

Note: Set it with the decimal value, it will return the hex value. The address is used to write or read and will clear the transmit Buffer.

## /0/i1buff 0..255\[,0..255\[,0..255\[,0..255\[,0..255\]\]\]\]

Add up to five bytes to I2C transmit buffer. JSON reply is the full buffer. 

``` 
/1/i1buff 2,0
{"txBuffer[2]":[{"data":"0x2"},{"data":"0x0"}]}
``` 

## /0/i1buff?

Show transmit buffer data that will be given to I2C master.

``` 
/1/i1buff?
{"txBuffer[2]":[{"data":"0x2"},{"data":"0x0"}]}
``` 

## /0/i1write

Attempt to become master and write the txBuffer bytes to I2C address. The txBuffer will clear if write was a success.

``` 
/1/i1addr 41
{"master_address":"0x29"}
/1/i1buff?
{"txBuffer[0]":[]}
/1/i1buff 2,0
{"txBuffer[2]":[{"data":"0x2"},{"data":"0x0"}]}
/1/i1write
{"error":"wrt_addr_nack"}
``` 

Welp what did you expect? Nothing is on the bus.

## /0/i1read? \[1..32\]

If txBuffer is empty, attempt to become master write zero bytes to chekc for NACK and then obtain readings into rxBuffer.

``` 
/1/i1addr 41
{"master_address":"0x29"}
/1/i1buff?
{"txBuffer[0]":[]}
/1/i1buff 2,0
{"txBuffer[2]":[{"data":"0x2"},{"data":"0x0"}]}
/1/i1write
{"error":"wrt_addr_nack"}
/1/i1buff?
{"txBuffer[2]":[{"data":"0x2"},{"data":"0x0"}]}
/1/i1addr 41
{"master_address":"0x29"}
/1/i1buff?
{"txBuffer[0]":[]}
/1/i1read? 2
{"error":"rd_addr_nack"}
``` 

If txBuffer has values, attempt to become master and write the byte(s) in buffer (e.g., a command byte) to I2C address without a stop condition. The txBuffer will clear if write was a success. Then send a repeated Start condition, followed by address and obtain readings into rxBuffer.

``` 
/1/i1addr 41
{"master_address":"0x29"}
/1/i1buff 2,0
{"txBuffer[2]":[{"data":"0x2"},{"data":"0x0"}]}
/1/i1read? 2
{"error":"wrt_addr_nack"}
``` 

This way of doing the repeated start allows testing SMBus block commands, which need a command byte sent before a repeated start and finally reading the data block.

## /0/i1mon? \[7..119\]

Monitor a slave address. The receive callback (from master write) fills a print buffer and a local buffer for an echo of the data back during a transmit callback (to master read). Loading the print buffer will be skipped when the UART is writing.

``` 
/1/i1mon? 28
{"monitor_0x1C":[{"data":"0x2"},{"data":"0x0"}]}
{"monitor_0x1C":[{"data":"0x0"},{"data":"0x0"}]}
``` 

The monitor events are from another board with i2c0-debug where I used a master to write to this slave.

```
/0/iscan?
{"scan":[{"addr":"0x1C"},{"addr":"0x29"}]}
/0/iaddr 28
{"address":"0x1C"}
/0/ibuff 2,0
{"txBuffer[2]":[{"data":"0x2"},{"data":"0x0"}]}
/0/iread? 2
{"rxBuffer":[{"data":"0x2"},{"data":"0x0"}]}
/0/ibuff 0,0
{"txBuffer[2]":[{"data":"0x0"},{"data":"0x0"}]}
/0/iread? 2
{"rxBuffer":[{"data":"0x0"},{"data":"0x0"}]}
``` 

## [i2c0-debug](../i2c0-debug#commands)

i2c0-debug is included with this build

# PCA9554 Example

Load the PCA9554 configuration register 3 (DDR) with zero to set the port as output. Then alternate register 1 (the output port) with 85 and 170 to toggle its output pins. 

``` 
/1/iaddr 56
{"address":"0x38"}
/1/ibuff 3,0
{"txBuffer":["data":"0x3","data":"0x0"]}
/1/iwrite
{"returnCode":"success"}
/1/ibuff 1,170
{"txBuffer":[{"data":"0x1"},{"data":"0xAA"}]}
/1/iwrite
{"returnCode":"success"}
/1/ibuff 1,85
{"txBuffer":[{"data":"0x1"},{"data":"0x55"}]}
/1/iwrite
{"returnCode":"success"}
``` 

# HTU21D Example 

``` 
/1/scan?
{"scan":[{"addr":"0x29"},{"addr":"0x40"}]}
``` 

Command 0xE3 measures temperature, the clock is streached until data is ready.

``` 
/1/iaddr 64
{"address":"0x40"}
/1/ibuff 227
{"txBuffer":["data":"0xE3"]}
/1/iread? 3
{"rxBuffer":[{"data":"0x6A"},{"data":"0xC"},{"data":"0xC6"}]}
``` 

The first two bytes are the temperature data. The last two bits of LSB are status (ignore or mask them off). Some Python gives the result in deg C.

``` 
Stmp = 0x6A0C
Temp = -46.85 + 175.72 * Stmp / (2**16)
Temp
25.9
``` 

Command 0xE5 measures humidity, again the clock is streached until data is ready.

``` 
/1/iaddr 64
{"address":"0x40"}
/1/ibuff 229
{"txBuffer":["data":"0xE5"]}
/1/read? 3
{"rxBuffer":[{"data":"0x65"},{"data":"0x96"},{"data":"0xBC"}]}
``` 

The first two bytes are the temperature data. The last two bits of LSB are status (ignore or mask them off). Some Python gives the result in deg C.

``` 
Stmp = 0x6596 & 0xFFFC
RH = -6 + 125 * Stmp / (2**16)
RH
43.6
```

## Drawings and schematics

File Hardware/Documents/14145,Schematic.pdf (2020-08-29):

## USB SBC (R-PI) HDR FOR DEBUGING RPU TARGET

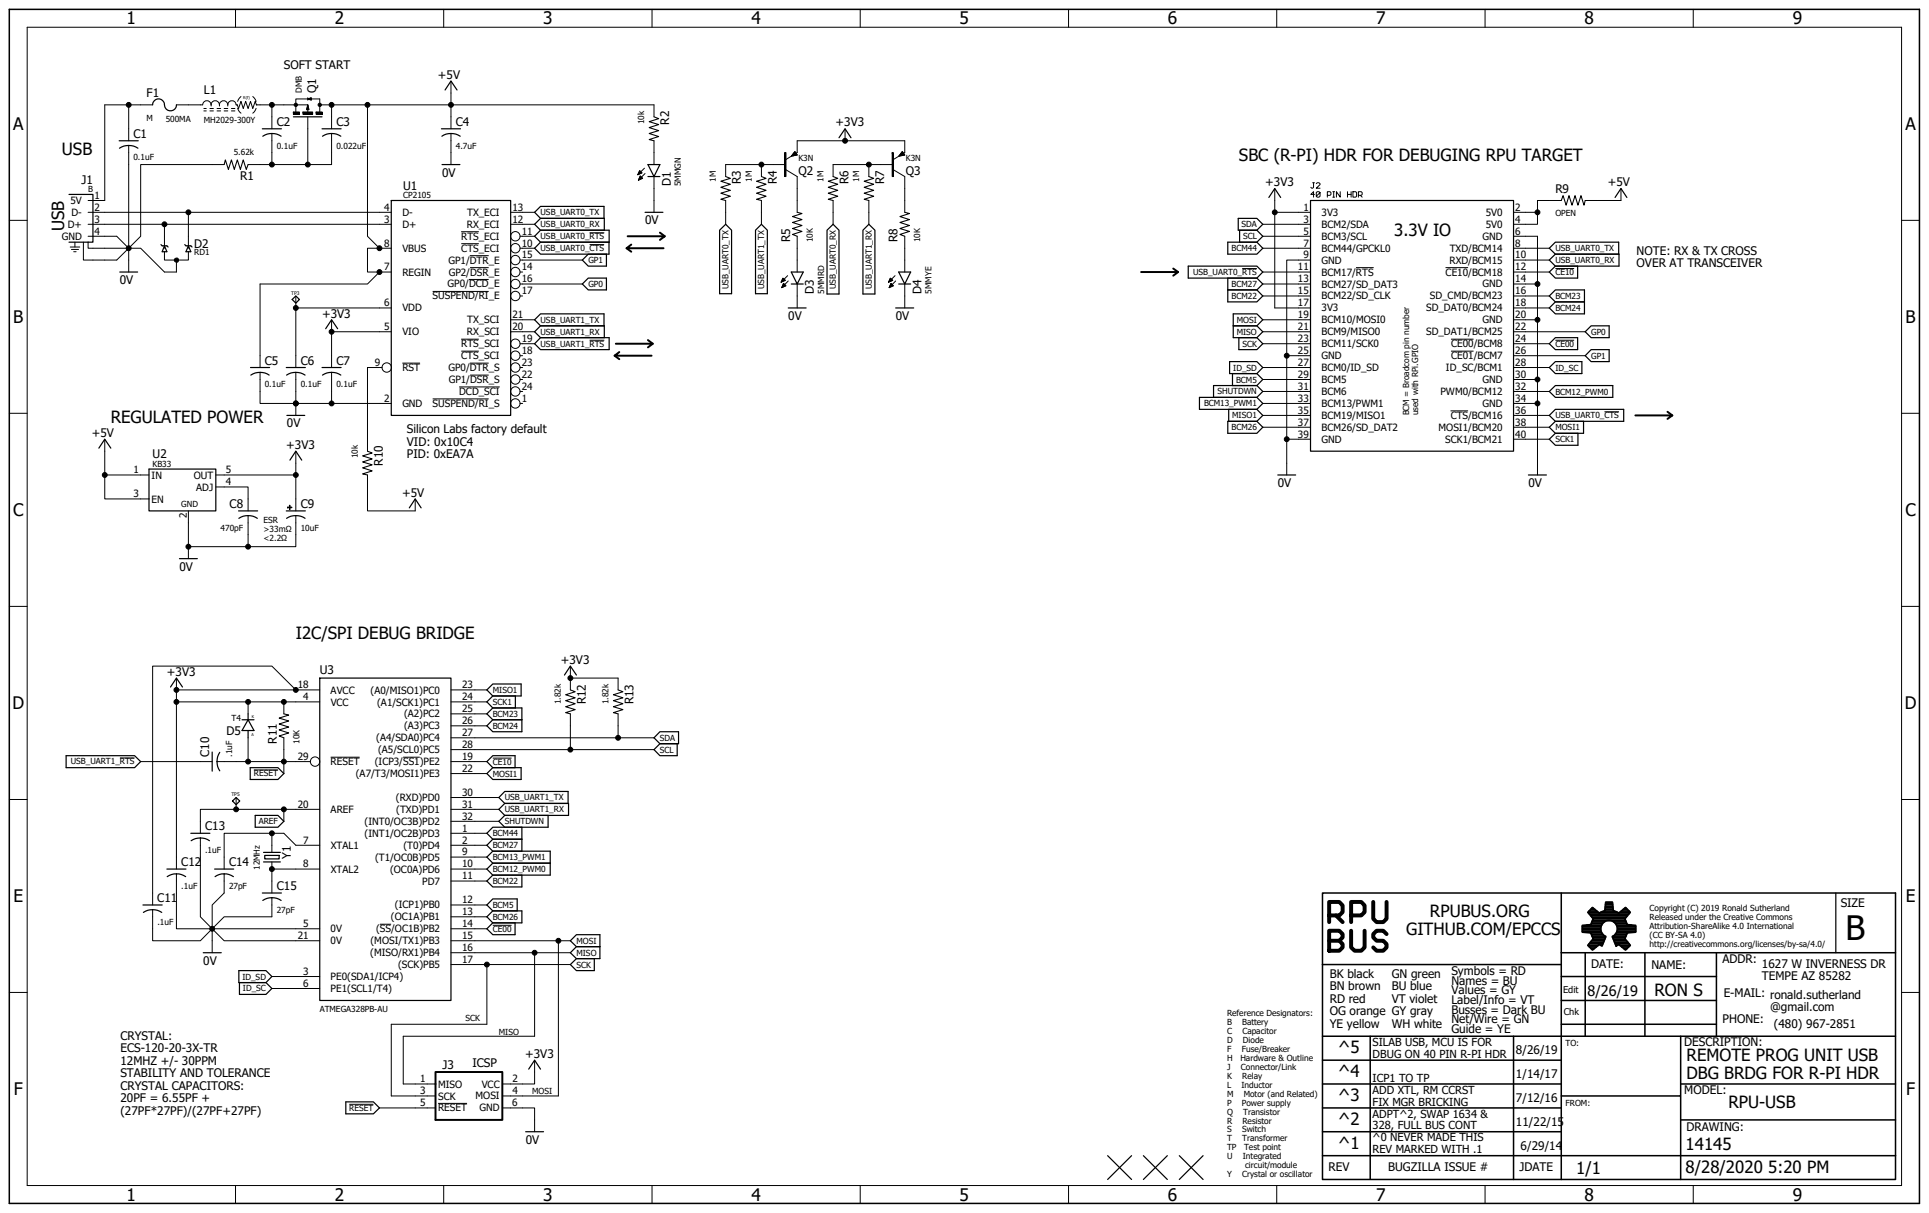
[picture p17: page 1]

NOTE: RX & TX CROSS
OVER AT TRANSCEIVER

BCM = Broadcom pin number

used with RPi.GPIO

Silicon Labs factory default
VID: 0x10C4
PID: 0xEA7A

Copyright (C) 2019 Ronald Sutherland
Released under the Creative Commons
Attribution-ShareAlike 4.0 International
http://creativecommons.org/licenses/by-sa/4.0/

Edit | 8/26/19 | RON S

Chk

DBUG ON 40 PIN R-PI HDR | 8/26/19 SILAB USB, MCU IS FOR ^5 | TO: | DESCRIPTION: REMOTE PROG UNIT USB DBG BRDG FOR R-PI HDR
^4 | ICP1 TO TP | 1/14/17
^3 | ADD XTL, RM CCRST FIX MGR BRICKING | 7/12/16 | | MODEL: RPU-USB
^2 | ADPT^2, SWAP 1634 & 328, FULL BUS CONT | 11/22/15

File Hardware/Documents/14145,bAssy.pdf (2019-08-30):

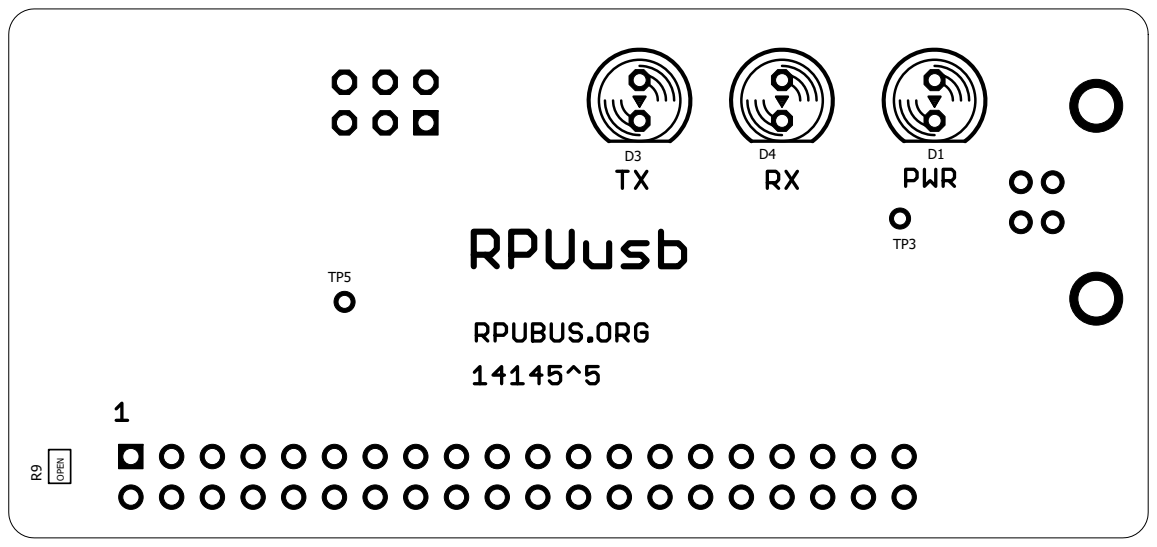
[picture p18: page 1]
OPEN

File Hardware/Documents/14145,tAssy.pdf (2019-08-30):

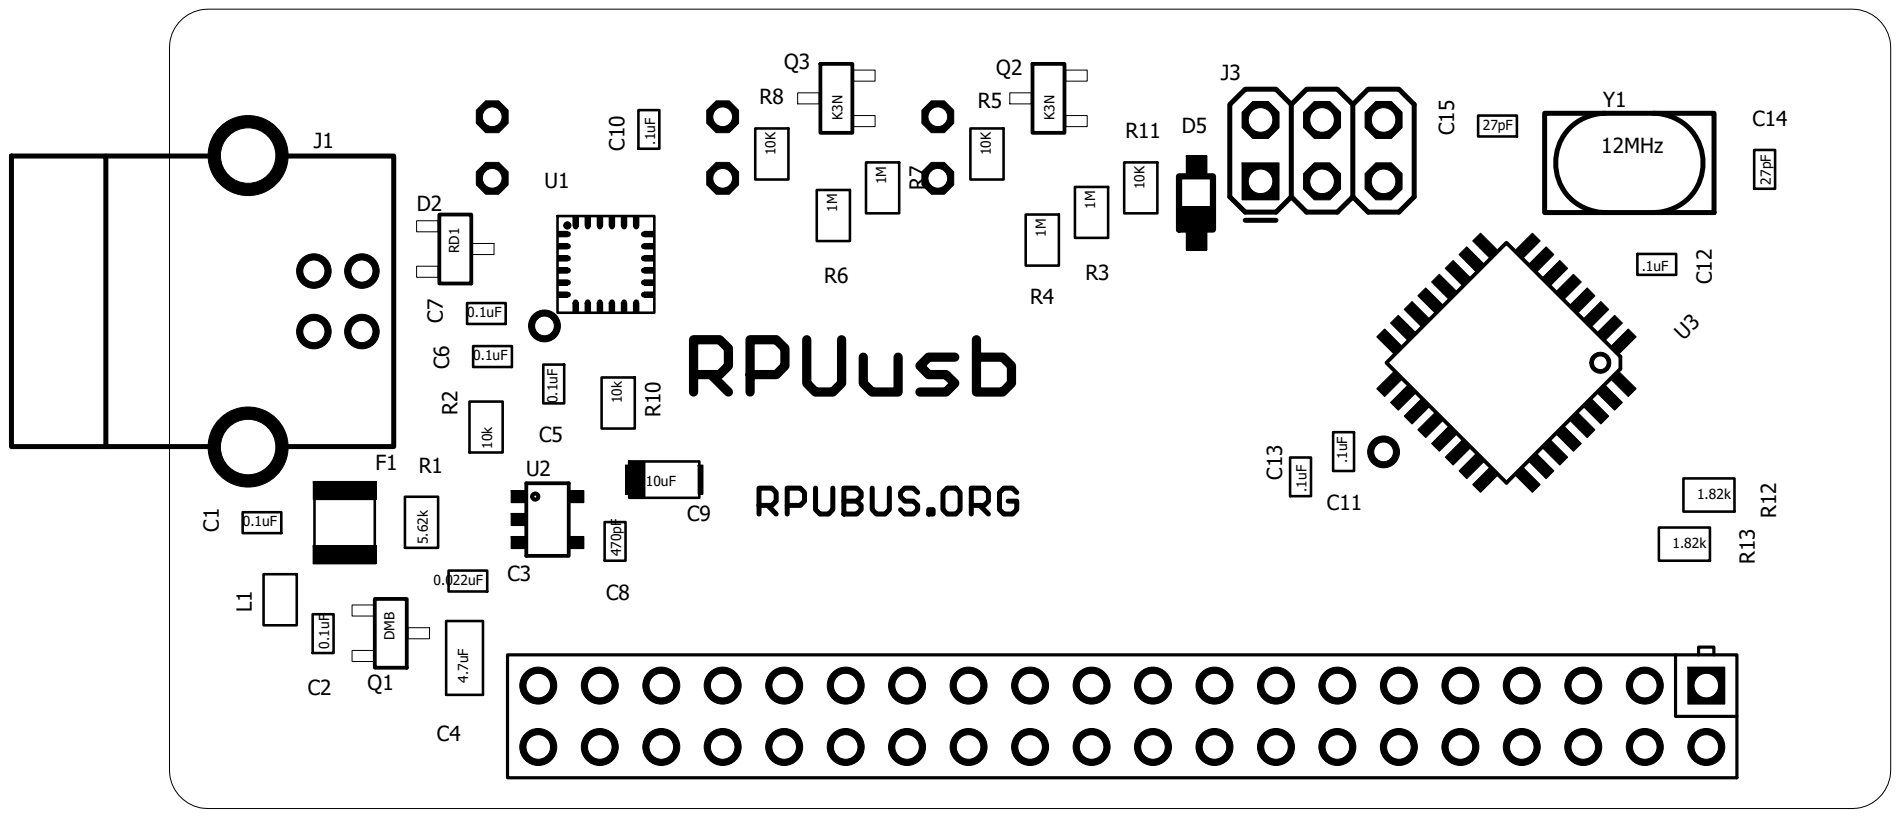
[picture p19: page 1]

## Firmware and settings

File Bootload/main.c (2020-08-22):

#define FUNC_READ 1
#define FUNC_WRITE 1
/*
Serial bootloader
Copyright 2017 by Ronald Sutherland 

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
You should have received a copy of the GNU General
Public License along with this program; if not, write 
to the Free Software Foundation, Inc., 
59 Temple Place, Suite 330, Boston, MA  02111-1307 USA 

Licence can be viewed at
http://www.fsf.org/licenses/gpl.txt

Bootloader Exception: In addition to the permissions in the 
GNU General Public License, the authors give you unlimited 
permission to link or embed compiled bootloader and related 
files into combinations with other programs, and to distribute 
those combinations without any restriction coming from the 
use of those files. (The General Public License restrictions do 
apply in other respects; for example, they cover modification 
of the files, and distribution when not linked into a combined 
executable.)

https://spdx.org/licenses/Bootloader-exception.html#licenseExceptionText

Based on optiboot which is GPL and 
Copyright 2013-2015 by Bill Westfield. 
Copyright 2010 by Peter Knight. 

For the original version see https://github.com/majekw/optiboot
*/

/*  Optional   
BIGBOOT: Build a 1k bootloader, not 512 bytes. This turns on extra functionality. 
BAUD: Set bootloader baud rate.
SOFT_UART: Use AVR305 soft-UART instead of hardware UART.
LED_START_FLASHES: Number of LED flashes on bootup.
LED_DATA_FLASH: Flash LED when transferring data.
SUPPORT_EEPROM: Support reading and writing from EEPROM. This is not used by Arduino, so off by default. 
TIMEOUT_MS: Bootloader timeout period, in milliseconds. 500,1000,2000,4000,8000 supported. 
UART: UART number (0..n) for devices with more than one hardware uart (644P, 1284P, etc) 
*/

/*  fuses could be set in the code rather than makefile https://www.avrfreaks.net/forum/how-embed-fuses-c-xmega
FUSES = {
          .low =      0xFF,
          .high =     0xDE,
          .extended = 0xFD,
        };
*/

#define OPTIBOOT_MAJVER 6
#define OPTIBOOT_MINVER 2

unsigned const int __attribute__((section(".version"))) 
optiboot_version = 256*(OPTIBOOT_MAJVER) + OPTIBOOT_MINVER;

#include <inttypes.h>
#include <avr/io.h>
#include <avr/pgmspace.h>
#include <avr/eeprom.h>

/* Note that optiboot has its own version of "boot.h" */
#include "boot.h"
#include "pin_defs.h"

/* stk500.h contains the constant definitions for the stk500v1 protocol used by avrdude */
#include "stk500.h"

#ifndef LED_START_FLASHES
#define LED_START_FLASHES 0
#endif

/* set the UART baud rate defaults */
#ifndef BAUD
#if F_CPU >= 8000000L
#define BAUD   115200L // Highest rate Avrdude win32 will support
#elif F_CPU >= 1000000L
#define BAUD   9600L   // 19200 also supported, but with significant error
#elif F_CPU >= 128000L
#define BAUD   4800L   // Good for 128kHz internal RC
#else
#define BAUD 1200L     // Good even at 32768Hz
#endif
#endif

#ifndef UART
#define UART 0
#endif

#define BAUD_SETTING (( (F_CPU + BAUD * 4L) / ((BAUD * 8L))) - 1 )
#define BAUD_ACTUAL (F_CPU/(8 * ((BAUD_SETTING)+1)))
#if BAUD_ACTUAL <= BAUD
  #define BAUD_ERROR (( 100*(BAUD - BAUD_ACTUAL) ) / BAUD)
  #if BAUD_ERROR >= 5
    #error BAUD error greater than -5%
  #elif BAUD_ERROR >= 2
    #warning BAUD error greater than -2%
  #endif
#else
  #define BAUD_ERROR (( 100*(BAUD_ACTUAL - BAUD) ) / BAUD)
  #if BAUD_ERROR >= 5
    #error BAUD error greater than 5%
  #elif BAUD_ERROR >= 2
    #warning BAUD error greater than 2%
  #endif
#endif

#if (F_CPU + BAUD * 4L) / (BAUD * 8L) - 1 > 250
#error Unachievable baud rate (too slow) BAUD 
#endif // baud rate slow check
#if (F_CPU + BAUD * 4L) / (BAUD * 8L) - 1 < 3
#if BAUD_ERROR != 0 // permit high bitrates (ie 1Mbps@16MHz) if error is zero
#error Unachievable baud rate (too fast) BAUD 
#endif
#endif // baud rate fastn check

/* Watchdog settings */
#define WATCHDOG_OFF    (0)
#define WATCHDOG_16MS   (_BV(WDE))
#define WATCHDOG_32MS   (_BV(WDP0) | _BV(WDE))
#define WATCHDOG_64MS   (_BV(WDP1) | _BV(WDE))
#define WATCHDOG_125MS  (_BV(WDP1) | _BV(WDP0) | _BV(WDE))
#define WATCHDOG_250MS  (_BV(WDP2) | _BV(WDE))
#define WATCHDOG_500MS  (_BV(WDP2) | _BV(WDP0) | _BV(WDE))
#define WATCHDOG_1S     (_BV(WDP2) | _BV(WDP1) | _BV(WDE))
#define WATCHDOG_2S     (_BV(WDP2) | _BV(WDP1) | _BV(WDP0) | _BV(WDE))
#ifndef __AVR_ATmega8__
#define WATCHDOG_4S     (_BV(WDP3) | _BV(WDE))
#define WATCHDOG_8S     (_BV(WDP3) | _BV(WDP0) | _BV(WDE))
#endif


/*
 * We can never load flash with more than 1 page at a time, so we can save
 * some code space on parts with smaller pagesize by using a smaller int.
 */
#if SPM_PAGESIZE > 255
typedef uint16_t pagelen_t ;
#define GETLENGTH(len) len = getch()<<8; len |= getch()
#else
typedef uint8_t pagelen_t;
#define GETLENGTH(len) (void) getch() /* skip high byte */; len = getch()
#endif


/* Function Prototypes
 * The main() function is in init9, which removes the interrupt vector table
 * we don't need. It is also 'OS_main', which means the compiler does not
 * generate any entry or exit code itself (but unlike 'naked', it doesn't
 * supress some compile-time options we want.)
 */

void pre_main(void) __attribute__ ((naked)) __attribute__ ((section (".init8")));
int main(void) __attribute__ ((OS_main)) __attribute__ ((section (".init9")));

void __attribute__((noinline)) putch(char);
uint8_t __attribute__((noinline)) getch(void);
void __attribute__((noinline)) verifySpace();
void __attribute__((noinline)) watchdogConfig(uint8_t x);

static inline void getNch(uint8_t);
#if LED_START_FLASHES > 0
static inline void flash_led(uint8_t);
#endif
static inline void watchdogReset();
static inline void writebuffer(int8_t memtype, uint8_t *mybuff,
			       uint16_t address, pagelen_t len);
static inline void read_mem(uint8_t memtype,
			    uint16_t address, pagelen_t len);
static void __attribute__((noinline)) do_spm(uint16_t address, uint8_t command, uint16_t data);

#ifdef SOFT_UART
void uartDelay() __attribute__ ((naked));
#endif
void appStart(uint8_t rstFlags) __attribute__ ((naked));

/*
 * RAMSTART should be self-explanatory.  It's bigger on parts with a
 * lot of peripheral registers.  Let 0x100 be the default
 * Note that RAMSTART (for optiboot) need not be exactly at the start of RAM.
 */
#if !defined(RAMSTART)  // newer versions of gcc avr-libc define RAMSTART
#define RAMSTART 0x100
#if defined (__AVR_ATmega644P__)
// correct for a bug in avr-libc
#undef SIGNATURE_2
#define SIGNATURE_2 0x0A
#elif defined(__AVR_ATmega1280__)
#undef RAMSTART
#define RAMSTART (0x200)
#endif
#endif

// Make sure all variants gets the correct device signature
#if defined(__AVR_ATmega88__)
	#undef SIGNATURE_2
	#define SIGNATURE_2 0x0A
#elif defined(__AVR_ATmega88p__)
	#undef SIGNATURE_2
	#define SIGNATURE_2 0x0F
#elif defined(__AVR_ATmega168__)
	#undef SIGNATURE_2
	#define SIGNATURE_2 0x06
#elif defined(__AVR_ATmega168p__)
	#undef SIGNATURE_2
	#define SIGNATURE_2 0x0B
#elif defined(__AVR_ATmega328__)
	#undef SIGNATURE_2
	#define SIGNATURE_2 0x14
#elif defined(__AVR_ATmega328p__)
	#undef SIGNATURE_2
	#define SIGNATURE_2 0x0F	
#endif	
	

/* C zero initialises all global variables. However, that requires */
/* These definitions are NOT zero initialised, but that doesn't matter */
/* This allows us to drop the zero init code, saving us memory */
#define buff    ((uint8_t*)(RAMSTART))

/* Virtual boot partition support */
#ifdef VIRTUAL_BOOT_PARTITION
#define rstVect0_sav (*(uint8_t*)(RAMSTART+SPM_PAGESIZE*2+4))
#define rstVect1_sav (*(uint8_t*)(RAMSTART+SPM_PAGESIZE*2+5))
#define saveVect0_sav (*(uint8_t*)(RAMSTART+SPM_PAGESIZE*2+6))
#define saveVect1_sav (*(uint8_t*)(RAMSTART+SPM_PAGESIZE*2+7))
// Vector to save original reset jump:
//   SPM Ready is least probably used, so it's default
//   if not, use old way WDT_vect_num,
//   or simply set custom save_vect_num in Makefile using vector name
//   or even raw number.
#if !defined (save_vect_num)
#if defined (SPM_RDY_vect_num)
#define save_vect_num (SPM_RDY_vect_num)
#elif defined (SPM_READY_vect_num)
#define save_vect_num (SPM_READY_vect_num)
#elif defined (WDT_vect_num)
#define save_vect_num (WDT_vect_num)
#else
#error Cant find SPM or WDT interrupt vector for this CPU
#endif
#endif //save_vect_num
// check if it's on the same page (code assumes that)
#if (SPM_PAGESIZE <= save_vect_num)
#error Save vector not in the same page as reset!
#endif
#if FLASHEND > 8192
// AVRs with more than 8k of flash have 4-byte vectors, and use jmp.
//  We save only 16 bits of address, so devices with more than 128KB
//  may behave wrong for upper part of address space.
#define rstVect0 2
#define rstVect1 3
#define saveVect0 (save_vect_num*4+2)
#define saveVect1 (save_vect_num*4+3)
#define appstart_vec (save_vect_num*2)
#else
// AVRs with up to 8k of flash have 2-byte vectors, and use rjmp.
#define rstVect0 0
#define rstVect1 1
#define saveVect0 (save_vect_num*2)
#define saveVect1 (save_vect_num*2+1)
#define appstart_vec (save_vect_num)
#endif
#else
#define appstart_vec (0)
#endif // VIRTUAL_BOOT_PARTITION

/* everything that needs to run VERY early */
void pre_main(void) {
  // Allow convenient way of calling do_spm function - jump table,
  //   so entry to this function will always be here, indepedent of compilation,
  //   features etc
  asm volatile (
    "	rjmp	1f\n"
    /*"	rjmp	do_spm\n" */ // RSS: not useful and makes hacking to predictable.
    "1:\n"
  );
}


/* main program starts here */
int main(void) {
  uint8_t ch;

  /*
   * Making these local and in registers prevents the need for initializing
   * them, and also saves space because code no longer stores to memory.
   * (initializing address keeps the compiler happy, but isn't really
   *  necessary, and uses 4 bytes of flash.)
   */
  register uint16_t address = 0;
  register pagelen_t  length;

  // After the zero init loop, this is the first code to run.
  //
  // This code makes the following assumptions:
  //  No interrupts will execute
  //  SP points to RAMEND
  //  r1 contains zero
  //
  // If not, uncomment the following instructions:
  // cli();
  asm volatile ("clr __zero_reg__");
#if defined(__AVR_ATmega8__) || defined (__AVR_ATmega32__) || defined (__AVR_ATmega16__)
  SP=RAMEND;  // This is done by hardware reset
#endif

  /*
   * Protect as much from MCUSR as possible for application
   * and still skip bootloader if not necessary
   * 
   * Code by MarkG55
   * see discusion in https://github.com/Optiboot/optiboot/issues/97
   */
#if !defined(__AVR_ATmega16__)
  ch = MCUSR;
#else
  ch = MCUCSR;
#endif
  // Skip all logic and run bootloader if MCUSR is cleared (application request)
  if (ch != 0) {
    /*
     * To run the boot loader, External Reset Flag must be set.
     * If not, we could make shortcut and jump directly to application code.
     * Also WDRF set with EXTRF is a result of Optiboot timeout, so we
     * shouldn't run bootloader in loop :-) That's why:
     *  1. application is running if WDRF is cleared
     *  2. we clear WDRF if it's set with EXTRF to avoid loops
     * One problematic scenario: broken application code sets watchdog timer 
     * without clearing MCUSR before and triggers it quickly. But it's
     * recoverable by power-on with pushed reset button.
     */
    if ((ch & (_BV(WDRF) | _BV(EXTRF))) != _BV(EXTRF)) { 
      if (ch & _BV(EXTRF)) {
        /*
         * Clear WDRF because it was most probably set by wdr in bootloader.
         * It's also needed to avoid loop by broken application which could
         * prevent entering bootloader.
         * '&' operation is skipped to spare few bytes as bits in MCUSR
         * can only be cleared.
         */
#if !defined(__AVR_ATmega16__)
        MCUSR = ~(_BV(WDRF));  
#else
        MCUCSR = ~(_BV(WDRF));  
#endif
      }
      appStart(ch);
    }
  }
  
#if LED_START_FLASHES > 0
  // Set up Timer 1 for timeout counter
  TCCR1B = _BV(CS12) | _BV(CS10); // div 1024
#endif

#ifndef SOFT_UART
#if defined(__AVR_ATmega8__) || defined (__AVR_ATmega32__) || defined (__AVR_ATmega16__)
  UCSRA = _BV(U2X); //Double speed mode USART
  UCSRB = _BV(RXEN) | _BV(TXEN);  // enable Rx & Tx
  UCSRC = _BV(URSEL) | _BV(UCSZ1) | _BV(UCSZ0);  // config USART; 8N1
  UBRRL = (uint8_t)( (F_CPU + BAUD * 4L) / (BAUD * 8L) - 1 );
#else
  UART_SRA = _BV(U2X0); //Double speed mode USART0
  UART_SRB = _BV(RXEN0) | _BV(TXEN0);
  UART_SRC = _BV(UCSZ00) | _BV(UCSZ01);
  UART_SRL = (uint8_t)( (F_CPU + BAUD * 4L) / (BAUD * 8L) - 1 );
#endif
#endif

  // Set up watchdog to trigger after 1s
  watchdogConfig(WATCHDOG_2S);

#if (LED_START_FLASHES > 0) || defined(LED_DATA_FLASH)
  /* Set LED pin as output */
  LED_DDR |= _BV(LED);
#endif

#ifdef SOFT_UART
  /* Set TX pin as output */
  UART_DDR |= _BV(UART_TX_BIT);
#endif

#if LED_START_FLASHES > 0
  /* Flash onboard LED to signal entering of bootloader */
  flash_led(LED_START_FLASHES * 2);
#endif

  /* Forever loop: exits by causing WDT reset */
  for (;;) {
    /* get character from UART */
    ch = getch();

    if(ch == STK_GET_PARAMETER) {
      unsigned char which = getch();
      verifySpace();
      /*
       * Send optiboot version as "SW version"
       * Note that the references to memory are optimized away.
       */
      if (which == STK_SW_MINOR) {
	  putch(optiboot_version & 0xFF);
      } else if (which == STK_SW_MAJOR) {
	  putch(optiboot_version >> 8);
      } else {
	/*
	 * GET PARAMETER returns a generic 0x03 reply for
         * other parameters - enough to keep Avrdude happy
	 */
	putch(0x03);
      }
    }
    else if(ch == STK_SET_DEVICE) {
      // SET DEVICE is ignored
      getNch(20);
    }
    else if(ch == STK_SET_DEVICE_EXT) {
      // SET DEVICE EXT is ignored
      getNch(5);
    }
    else if(ch == STK_LOAD_ADDRESS) {
      // LOAD ADDRESS
      uint16_t newAddress;
      newAddress = getch();
      newAddress = (newAddress & 0xff) | (getch() << 8);
#ifdef RAMPZ
      // Transfer top bit to LSB in RAMPZ
      if (newAddress & 0x8000) {
        RAMPZ |= 0x01;
      }
      else {
        RAMPZ &= 0xFE;
      }
#endif
      newAddress += newAddress; // Convert from word address to byte address
      address = newAddress;
      verifySpace();
    }
    else if(ch == STK_UNIVERSAL) {
#ifdef RAMPZ
      // LOAD_EXTENDED_ADDRESS is needed in STK_UNIVERSAL for addressing more than 128kB
      if ( AVR_OP_LOAD_EXT_ADDR == getch() ) {
        // get address
        getch();  // get '0'
        RAMPZ = (RAMPZ & 0x01) | ((getch() << 1) & 0xff);  // get address and put it in RAMPZ
        getNch(1); // get last '0'
        // response
        putch(0x00);
      }
      else {
        // everything else is ignored
        getNch(3);
        putch(0x00);
      }
#else
      // UNIVERSAL command is ignored
      getNch(4);
      putch(0x00);
#endif
    }
    /* Write memory, length is big endian and is in bytes */
    else if(ch == STK_PROG_PAGE) {
      // PROGRAM PAGE - we support flash programming only, not EEPROM
      uint8_t desttype;
      uint8_t *bufPtr;
      pagelen_t savelength;

      GETLENGTH(length);
      savelength = length;
      desttype = getch();

      // read a page worth of contents
      bufPtr = buff;
      do *bufPtr++ = getch();
      while (--length);

      // Read command terminator, start reply
      verifySpace();

#ifdef VIRTUAL_BOOT_PARTITION
#if FLASHEND > 8192
/*
 * AVR with 4-byte ISR Vectors and "jmp"
 * WARNING: this works only up to 128KB flash!
 */
      if (address == 0) {
	// This is the reset vector page. We need to live-patch the
	// code so the bootloader runs first.
	//
	// Save jmp targets (for "Verify")
	rstVect0_sav = buff[rstVect0];
	rstVect1_sav = buff[rstVect1];
	saveVect0_sav = buff[saveVect0];
	saveVect1_sav = buff[saveVect1];

        // Move RESET jmp target to 'save' vector
        buff[saveVect0] = rstVect0_sav;
        buff[saveVect1] = rstVect1_sav;

        // Add jump to bootloader at RESET vector
        // WARNING: this works as long as 'main' is in first section
        buff[rstVect0] = ((uint16_t)main) & 0xFF;
        buff[rstVect1] = ((uint16_t)main) >> 8;
      }

#else
/*
 * AVR with 2-byte ISR Vectors and rjmp
 */
      if ((uint16_t)(void*)address == rstVect0) {
        // This is the reset vector page. We need to live-patch
        // the code so the bootloader runs first.
        //
        // Move RESET vector to 'save' vector
	// Save jmp targets (for "Verify")
	rstVect0_sav = buff[rstVect0];
	rstVect1_sav = buff[rstVect1];
	saveVect0_sav = buff[saveVect0];
	saveVect1_sav = buff[saveVect1];

	// Instruction is a relative jump (rjmp), so recalculate.
	uint16_t vect=(rstVect0_sav & 0xff) | ((rstVect1_sav & 0x0f)<<8); //calculate 12b displacement
	vect = (vect-save_vect_num) & 0x0fff; //substract 'save' interrupt position and wrap around 4096
        // Move RESET jmp target to 'save' vector
        buff[saveVect0] = vect & 0xff;
        buff[saveVect1] = (vect >> 8) | 0xc0; //
        // Add rjump to bootloader at RESET vector
        vect = ((uint16_t)main) &0x0fff; //WARNIG: this works as long as 'main' is in first section
        buff[0] = vect & 0xFF; // rjmp 0x1c00 instruction
	buff[1] = (vect >> 8) | 0xC0;
      }
#endif // FLASHEND
#endif // VBP

      writebuffer(desttype, buff, address, savelength);


    }
    /* Read memory block mode, length is big endian.  */
    else if(ch == STK_READ_PAGE) {
      uint8_t desttype;
      GETLENGTH(length);

      desttype = getch();

      verifySpace();

      read_mem(desttype, address, length);
    }

    /* Get device signature bytes  */
    else if(ch == STK_READ_SIGN) {
      // READ SIGN - return what Avrdude wants to hear
      verifySpace();
      putch(SIGNATURE_0);
      putch(SIGNATURE_1);
      putch(SIGNATURE_2);
    }
    else if (ch == STK_LEAVE_PROGMODE) { /* 'Q' */
      // Adaboot no-wait mod
      watchdogConfig(WATCHDOG_16MS);
      verifySpace();
    }
    else {
      // This covers the response to commands like STK_ENTER_PROGMODE
      verifySpace();
    }
    putch(STK_OK);
  }
}

void putch(char ch) {
#ifndef SOFT_UART
  while (!(UART_SRA & _BV(UDRE0)));
  UART_UDR = ch;
#else
  __asm__ __volatile__ (
    "   com %[ch]\n" // ones complement, carry set
    "   sec\n"
    "1: brcc 2f\n"
    "   cbi %[uartPort],%[uartBit]\n"
    "   rjmp 3f\n"
    "2: sbi %[uartPort],%[uartBit]\n"
    "   nop\n"
    "3: rcall uartDelay\n"
    "   rcall uartDelay\n"
    "   lsr %[ch]\n"
    "   dec %[bitcnt]\n"
    "   brne 1b\n"
    :
    :
      [bitcnt] "d" (10),
      [ch] "r" (ch),
      [uartPort] "I" (_SFR_IO_ADDR(UART_PORT)),
      [uartBit] "I" (UART_TX_BIT)
    :
      "r25"
  );
#endif
}

uint8_t getch(void) {
  uint8_t ch;

#ifdef LED_DATA_FLASH
#if defined(__AVR_ATmega8__) || defined (__AVR_ATmega32__) || defined (__AVR_ATmega16__)
  LED_PORT ^= _BV(LED);
#else
  LED_PIN |= _BV(LED);
#endif
#endif

#ifdef SOFT_UART
    watchdogReset();
  __asm__ __volatile__ (
    "1: sbic  %[uartPin],%[uartBit]\n"  // Wait for start edge
    "   rjmp  1b\n"
    "   rcall uartDelay\n"          // Get to middle of start bit
    "2: rcall uartDelay\n"              // Wait 1 bit period
    "   rcall uartDelay\n"              // Wait 1 bit period
    "   clc\n"
    "   sbic  %[uartPin],%[uartBit]\n"
    "   sec\n"
    "   dec   %[bitCnt]\n"
    "   breq  3f\n"
    "   ror   %[ch]\n"
    "   rjmp  2b\n"
    "3:\n"
    :
      [ch] "=r" (ch)
    :
      [bitCnt] "d" (9),
      [uartPin] "I" (_SFR_IO_ADDR(UART_PIN)),
      [uartBit] "I" (UART_RX_BIT)
    :
      "r25"
);
#else
  while(!(UART_SRA & _BV(RXC0)))
    ;
  if (!(UART_SRA & _BV(FE0))) {
      /*
       * A Framing Error indicates (probably) that something is talking
       * to us at the wrong bit rate.  Assume that this is because it
       * expects to be talking to the application, and DON'T reset the
       * watchdog.  This should cause the bootloader to abort and run
       * the application "soon", if it keeps happening.  (Note that we
       * don't care that an invalid char is returned...)
       */
    watchdogReset();
  }

  ch = UART_UDR;
#endif

#ifdef LED_DATA_FLASH
#if defined(__AVR_ATmega8__) || defined (__AVR_ATmega32__) || defined (__AVR_ATmega16__)
  LED_PORT ^= _BV(LED);
#else
  LED_PIN |= _BV(LED);
#endif
#endif

  return ch;
}

#ifdef SOFT_UART
// AVR305 equation: #define UART_B_VALUE (((F_CPU/BAUD)-23)/6)
// Adding 3 to numerator simulates nearest rounding for more accurate baud rates
#define UART_B_VALUE (((F_CPU/BAUD)-20)/6)
#if UART_B_VALUE > 255
#error Baud rate too slow for soft UART
#endif

void uartDelay() {
  __asm__ __volatile__ (
    "ldi r25,%[count]\n"
    "1:dec r25\n"
    "brne 1b\n"
    "ret\n"
    ::[count] "M" (UART_B_VALUE)
  );
}
#endif

void getNch(uint8_t count) {
  do getch(); while (--count);
  verifySpace();
}

void verifySpace() {
  if (getch() != CRC_EOP) {
    watchdogConfig(WATCHDOG_16MS);    // shorten WD timeout
    while (1)			      // and busy-loop so that WD causes
      ;				      //  a reset and app start.
  }
  putch(STK_INSYNC);
}

#if LED_START_FLASHES > 0
void flash_led(uint8_t count) {
  do {
    TCNT1 = -(F_CPU/(1024*16));
    TIFR1 = _BV(TOV1);
    while(!(TIFR1 & _BV(TOV1)));
#if defined(__AVR_ATmega8__) || defined (__AVR_ATmega32__) || defined (__AVR_ATmega16__)
    LED_PORT ^= _BV(LED);
#else
    LED_PIN |= _BV(LED);
#endif
    watchdogReset();
  } while (--count);
}
#endif

// Watchdog functions. These are only safe with interrupts turned off.
void watchdogReset() {
  __asm__ __volatile__ (
    "wdr\n"
  );
}

void watchdogConfig(uint8_t x) {
  WDTCSR = _BV(WDCE) | _BV(WDE);
  WDTCSR = x;
}
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

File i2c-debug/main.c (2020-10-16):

/*
i2c-debug is a command line controled demonstration of the 2-wire Serial Interface
Copyright (C) 2016 Ronald Sutherland

Permission to use, copy, modify, and/or distribute this software for any purpose with or without fee is hereby granted.

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
https://en.wikipedia.org/wiki/BSD_licenses#0-clause_license_(%22Zero_Clause_BSD%22)
*/

#include <stdbool.h>
#include <avr/pgmspace.h>
#include <util/atomic.h>
#include <util/delay.h>
#include "../lib/parse.h"
#include "../lib/uart0_bsd.h"
#include "../lib/timers_bsd.h"
#include "../lib/twi0_bsd.h"
#include "../lib/twi1_bsd.h"
#include "../lib/io_enum_bsd.h"
#include "id.h"
#include "i2c0-scan.h"
#include "i2c0-cmd.h"
#include "i2c0-monitor.h"
#include "i2c1-scan.h"
#include "i2c1-cmd.h"
#include "i2c1-monitor.h"
#include "../UPDImode/mode.h"

#define BLINK_DELAY 1000UL
static char rpu_addr;

void ProcessCmd()
{ 
    if ( (strcmp_P( command, PSTR("/id?")) == 0) && ( (arg_count == 0) || (arg_count == 1)) )
    {
        Id("I2Cdebug^2");
    }
    if ( (strcmp_P( command, PSTR("/iscan?")) == 0) && (arg_count == 0) )
    {
        I2c0_scan();
    }
    if ( (strcmp_P( command, PSTR("/iaddr")) == 0) && (arg_count == 1) )
    {
        I2c0_address();
    }
    if ( (strcmp_P( command, PSTR("/ibuff")) == 0) )
    {
        I2c0_txBuffer();
    }
    if ( (strcmp_P( command, PSTR("/ibuff?")) == 0) && (arg_count == 0) )
    {
        I2c0_txBuffer();
    }
    if ( (strcmp_P( command, PSTR("/iwrite")) == 0) && (arg_count == 0) )
    {
        I2c0_write();
    }
    if ( (strcmp_P( command, PSTR("/iread?")) == 0) && (arg_count == 1) )
    {
        I2c0_read();
    }
    if ( (strcmp_P( command, PSTR("/imon?")) == 0) && (arg_count == 1) )
    {
        I2c0_monitor();
    }
    if ( (strcmp_P( command, PSTR("/i1scan?")) == 0) && (arg_count == 0) )
    {
        I2c1_scan();
    }
    if ( (strcmp_P( command, PSTR("/i1addr")) == 0) && (arg_count == 1) )
    {
        I2c1_address();
    }
    if ( (strcmp_P( command, PSTR("/i1buff")) == 0) )
    {
        I2c1_txBuffer();
    }
    if ( (strcmp_P( command, PSTR("/i1buff?")) == 0) && (arg_count == 0) )
    {
        I2c1_txBuffer();
    }
    if ( (strcmp_P( command, PSTR("/i1write")) == 0) && (arg_count == 0) )
    {
        I2c1_write();
    }
    if ( (strcmp_P( command, PSTR("/i1read?")) == 0) && (arg_count == 1) )
    {
        I2c1_read();
    }
    if ( (strcmp_P( command, PSTR("/i1mon?")) == 0) && (arg_count == 1) )
    {
        I2c1_monitor();
    }
    if ( (strcmp_P( command, PSTR("/updi")) == 0) && (arg_count == 0) )
    {
        UPDI_mode();
    }
    if ( (strcmp_P( command, PSTR("/uart")) == 0) && (arg_count == 0) )
    {
        UART_mode();
    }
}

void setup(void) 
{
    // Timer0 Fast PWM mode, Timer1 & Timer2 Phase Correct PWM mode.
    initTimers(); 
    // bug? uart0_init(0,0); // bootloader may have the UART enabled, a zero baudrate should disconnect it.
    
    /* Initialize UART to 38.4kbps, it returns a pointer to FILE so redirect of stdin and stdout works*/
    stderr = stdout = stdin = uart0_init(38400UL, UART0_RX_REPLACE_CR_WITH_NL);

    // BCM23 is used on my PiUPDI board to select UART mode.
    ioDir(MCU_IO_BCM23,DIRECTION_OUTPUT);
    ioWrite(MCU_IO_BCM23,LOGIC_LEVEL_HIGH); // put PiUPDI board in UART mode

    // BCM24 is used on my PiUPDI board to select UPDI mode.
    ioDir(MCU_IO_BCM24,DIRECTION_OUTPUT);
    ioWrite(MCU_IO_BCM24,LOGIC_LEVEL_LOW); // not in UPDI mode

    // manager delays (blocks) for 50mSec after power up so i2c is not running yet
    _delay_ms(60); 

    /* Initialize I2C */
    twi0_init(100000UL, TWI0_PINS_PULLUP); 
    twi1_init(100000UL, TWI1_PINS_PULLUP);

    /* Clear and setup the command buffer, (probably not needed at this point) */
    initCommandBuffer();

    // Enable global interrupts to start TIMER0 and UART ISR's
    sei(); 

    rpu_addr = '0'; // software was done for multi-drop bus, but this is not multi-drop so its address can not change.
    printf_P(PSTR("i2c-debug at addr %d: commands include\n\r"), rpu_addr);
    printf_P(PSTR("/0/id? \n\r"));
}

int main(void) 
{    
    setup(); 

    while(1) 
    {
        // check if character is available to assemble a command, e.g. non-blocking
        if ( (!command_done) && uart0_available() ) // command_done is an extern from parse.h
        {
            // get a character from stdin and use it to assemble a command
            AssembleCommand(getchar());

            // address is the ascii value for '0' note: a null address will terminate the command string. 
            StartEchoWhenAddressed(rpu_addr);
        }
        
        // check if a character is available, and if so flush transmit buffer and nuke the command in process.
        // A multi-drop bus can have another device start transmitting after getting an address byte so
        // the first byte is used as a warning, it is the onlly chance to detect a possible collision.
        if ( command_done && uart0_available() )
        {
            // dump the transmit buffer to limit a collision 
            uart0_empty();

            // turn off the slave monitors
            twi1_slaveAddress(0);
            twi0_slaveAddress(0);

            initCommandBuffer();
        }
        
        // finish echo of the command line befor starting a reply (or the next part of a reply)
        if ( command_done && uart0_availableForWrite() )
        {
            if ( !echo_on  )
            { // this happons when the address did not match 
                initCommandBuffer();
            }
            else
            {
                if (command_done == 1)  
                {
                    findCommand();
                    command_done = 10;
                }
                
                // do not overfill the serial buffer since that blocks looping, e.g. process a command in 32 byte chunks
                if ( (command_done >= 10) && (command_done < 250) )
                {
                     ProcessCmd();
                }
                else 
                {
                    initCommandBuffer();
                }
            }
         }
    }        
    return 0;
}

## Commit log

2016-08-28 CheckDTR: used for board testing
2016-09-04 Host2Remote: for ^3 send a byte from UART on DTR
    pair rather than toggling line
2016-09-06 Host2Remote: split into functions
    add TWI, and document some ideas to try
    add lockout and uart check to round robin
2016-09-07 Host2Remote: add I2C commands 2,3, and 5
2016-09-10 Host2Remote: sorting out issues
    add more feedback in the form of blinking lights
    [main.c]
2016-09-11 Host2Remote: updates from mercurial repo
    lockout everything if host is foreign but only mcu if host is local
    disconnect when DTR pair has byte > 0x7F, start idea of a bus error
    char is like an int8_t on AVR but I thunked with uint8_t
    need improved host_is_foreign logic this is borken
    [main.c]
2016-11-16 Hardware: add schematic
2016-11-18 Host2Remote: don't connect mcu if not rpu aware
    [14145,BOM.csv, 14145.brd, 14145.sch]
2017-01-02 Host2Remote: broadcast after I2C read of rpu_addr /w bootloader_started
2017-01-05 Host2Remote: add host shutdown using ICP1
    and move some files from hg repo
    [14145,BOM.csv, 14145.brd, 14145.sch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]
2017-01-12 ardware: convert test and evaluation html to markdown
    from epccs/boards
2017-01-15 Hardware: ^4 review
    [14145.brd, 14145.sch]
2017-01-24 Hardware: arrange parts and their references
    [14145,BOM.csv, 14145.brd, 14145.sch]
2017-01-24 Hardware: bom update, price is based on my order qty
    [14145,BOM.csv]
2017-01-24 example is a little more refined
    [MultiDrop.sch]
2017-01-26 Hardware: example
    [14145,BOM.csv, MultiDrop.sch]
2017-03-02 Hardware: ^4 assembly
    [14145,BOM.csv]
2017-03-26 Hardware: use 12MHz crystal, populate r5,r13,r22
    [14145,BOM.csv]
2017-05-23 Hardware: crystal capacitors, eagle is not for open hardware
    [14145,BOM.csv, 14145.brd, 14145.sch]
2017-05-26 Host2Remote: add lockout to status and rename rxBuffer as i2cBuffer
2017-10-01 Host2Remote: i2c command notes
2017-11-28 Hardware: update multidrop example
    [MultiDrop.sch]
2019-08-30 Hardware: ^5 layout remove arduino headers and add r-pi like interface
2019-08-30 Hardware: ^5 bom done, rdy for review
    [14145,BOM.csv, 14145BRD,BOM.csv, 14145HDR,BOM.csv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]
2019-09-28 Hardware: ^5 boards in hand
    [14145SMD,BOM.csv]
2020-08-21 Hardware: ^5 assy done test started
    [14145HDR,BOM.csv]
2020-08-22 remove serial bus manager files, that function is on application boards
2020-08-22 BlinkLED: working uart & twi, schematic nodes and io_enum match
2020-08-23 i2c-debug: twi0 and twi1, and smoke, manager on gravimetric damaged
    [i2c0-monitor.c]
2020-08-29 Hardware: pin names on schematic match io_enum
2020-08-30 BCM24cntl: bcm24 pin used with PiUPDI to select uart or updi
2020-09-27 i2c-debug: setup to test i2c on the MacGyver, make rule to cp hdr for VSCode
2020-10-15 UPDImode: was BCM24cntl but BCM23 added for uart mode
2020-10-16 i2c-debug: init mode pins

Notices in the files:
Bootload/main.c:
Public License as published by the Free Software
